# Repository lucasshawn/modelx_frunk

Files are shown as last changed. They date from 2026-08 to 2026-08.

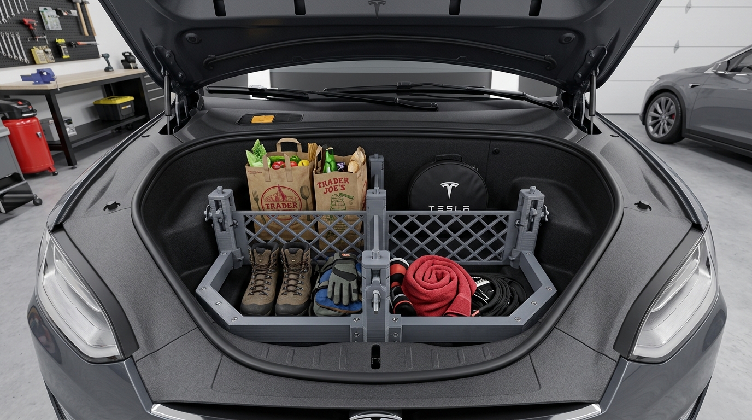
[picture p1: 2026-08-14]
docs/images/modelx_frunk_installed.jpg

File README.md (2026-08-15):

# Tesla Model X Frunk Modular Divider System
### Parametric CAD, 3D Printing & Assembly Architecture for Creality K2 Combo (350×350×350 mm)








---

## 1. Executive Summary & Project Overview

The **Tesla Model X Frunk Modular Divider System** is an open-source, production-grade automotive cargo management ecosystem engineered specifically for the deep front trunk (frunk) tub of the **2017 Tesla Model X (AWD configuration)**. 

Optimized for manufacturing on large-format, high-speed CoreXY 3D printers—specifically the **Creality K2 Combo / Plus** with its **350 × 350 × 350 mm** build volume and **60°C active heated chamber**—the system provides rigid, rattle-free compartmentalization for heavy charging cables (Tesla Mobile Connector, CCS adapters), portable tire inflators, roadside safety tools, groceries, and travel luggage.

```
+=============================================================================+
|                 TESLA MODEL X 2017 FRUNK DIVIDER SYSTEM HIGHLIGHTS          |
+=============================================================================+
|  Vehicle Compatibility:  2017 Tesla Model X (75D / 90D / 100D / P100D AWD)   |
|  Frunk Compartment:      Deep lower carpet tub (drop-in, zero vehicle mods)  |
|  Target 3D Printer:      Creality K2 Combo / Plus (350 × 350 × 350 mm)       |
|  CAD Automation Engine:  Autodesk Fusion 360 Python API (`fx` Parametric)    |
|  Standard Grid Pitch:    12.0 in (304.8 mm) Bay Spacing × 11.0 in (280.0 mm) |
|  Primary Material:       ASA (Acrylonitrile Styrene Acrylate) - UV & Heat 105°C|
|  Joint Mechanics:        15° Sliding Dovetails + Transverse M5 Pin Locks     |
|  Support-Free Printing:  45° Self-Supporting Diamond Lattice (0 supports)   |
+=============================================================================+
```

---

## 2. System Architecture & Component Library

The divider framework utilizes a **3-tier interlocking mechanical architecture** that eliminates fasteners, screws, and glues while providing maximum structural stiffness against longitudinal braking forces ($\le 1.2\text{ G}$) and lateral cornering loads ($\le 0.9\text{ G}$).

```
+=============================================================================+
|                      MODULAR 3-TIER SYSTEM ARCHITECTURE                     |
+=============================================================================+
|                                                                             |
|   [ Tier 3: Top Rails ]        ====== HR_Rail_12in ====== (Upper Tie Cap)   |
|                                         |           |                       |
|   [ Removable Dividers ]       [DIV_Crosshatch_12x11]  (45° Diamond Lattice)|
|                                         |           |                       |
|   [ Tier 2: Vertical Posts ]   |-- VR_Post_Deep --|  (6.4mm Guide Slots)    |
|                                 |                   |                       |
|   [ Tier 1: Floor Trusses ]    +-- FT_Segment_12in +  (Triangular Webs)     |
|                                 |                   |                       |
|   [ Modular Junctions ]      J_Corner_90 / J_Tee_3Way / J_Cross_4Way        |
|                                                                             |
|   [ Vibration Locks ]        Pin_Lock_M5 (Transverse Mechanical Dowels)     |
+=============================================================================+
```

```mermaid
graph TD
    subgraph Tier1["Tier 1: Base Foundation (Frunk Carpet)"]
        FT["FT_Segment_12in<br/>(12in Floor Truss with Triangular Webs)"]
        JC["J_Corner_90<br/>(2-Way Corner Block)"]
        JT["J_Tee_3Way<br/>(3-Way T-Junction)"]
        JX["J_Cross_4Way<br/>(4-Way Cross Junction)"]
        JC ---|15° Dovetail| FT
        JT ---|15° Dovetail| FT
        JX ---|15° Dovetail| FT
    end

    subgraph Tier2["Tier 2: Vertical Columns"]
        VR["VR_Post_Deep<br/>(11in Post with 6.4mm Guide Slots)"]
        FT -->|20x20mm Socket Tenon| VR
        JC -->|20x20mm Socket Tenon| VR
        JT -->|20x20mm Socket Tenon| VR
        JX -->|20x20mm Socket Tenon| VR
    end

    subgraph Panels["Removable Divider Panels"]
        DIV["DIV_Crosshatch_12x11<br/>(45° Diamond Lattice with Handle)"]
        VR -.->|Slide-in Engagement| DIV
    end

    subgraph Tier3["Tier 3: Upper Perimeter Tie"]
        HR["HR_Rail_12in<br/>(12in Horizontal Top Rail)"]
        VR -->|Top Cap Dovetail| HR
        DIV -.->|Top Channel Rest| HR
    end

    subgraph Fasteners["Vibration Security"]
        PIN["Pin_Lock_M5<br/>(Transverse Locking Pin)"]
        PIN -->|Locks Joint| FT
        PIN -->|Locks Joint| VR
    end

    style Tier1 fill:#f0f4f8,stroke:#2b6cb0,stroke-width:2px;
    style Tier2 fill:#ebf8ff,stroke:#3182ce,stroke-width:2px;
    style Tier3 fill:#e6fffa,stroke:#319795,stroke-width:2px;
    style Panels fill:#fffaf0,stroke:#dd6b20,stroke-width:2px;
    style Fasteners fill:#faf5ff,stroke:#805ad5,stroke-width:2px;
```

### Component Details & Specifications

| Component Identifier | Functional Role | Nominal Dimensions ($L \times W \times H$) | Key Geometric Features |
| :--- | :--- | :--- | :--- |
| **`FT_Segment_12in`** | Floor Truss Beam | $304.8 \times 24.0 \times 35.0\text{ mm}$ | 6 triangular weight-reduction cutouts, +X male dovetail, -X female dovetail, center post socket, 5.0mm pin bore |
| **`VR_Post_Deep`** | Vertical Rib Post | $24.0 \times 24.0 \times 280.0\text{ mm}$ | Dual opposing 6.4mm guide slots (8mm deep), bottom 20×20mm tenon, 5.0mm cross pin hole, top rail locator |
| **`HR_Rail_12in`** | Horizontal Top Rail | $304.8 \times 24.0 \times 24.0\text{ mm}$ | Bottom 6.4mm channel with 45° chamfer lead-in funnel, end male/female dovetails for top perimeter rigidity |
| **`J_Corner_90`** | 2-Way Corner Block | $32.0 \times 32.0 \times 35.0\text{ mm}$ | Dual orthogonal 15° dovetail tabs, central 20×20mm post socket, transverse 5.0mm pin hole |
| **`J_Tee_3Way`** | 3-Way T-Junction | $32.0 \times 32.0 \times 35.0\text{ mm}$ | 3-way 15° dovetail tabs, central 20×20mm post socket, transverse 5.0mm pin hole |
| **`J_Cross_4Way`** | 4-Way Cross Junction | $32.0 \times 32.0 \times 35.0\text{ mm}$ | 4-way 15° dovetail tabs, central 20×20mm post socket, transverse 5.0mm pin hole |
| **`DIV_Crosshatch_12x11`** | Slide-In Divider Panel | $298.0 \times 275.0 \times 5.0\text{ mm}$ | 10.0mm solid perimeter rim, 45° self-supporting diamond lattice (18mm pitch, 3.5mm struts), 80×22mm pull handle |
| **`Pin_Lock_M5`** | Transverse Locking Pin | $\varnothing 8.0\text{ mm cap} \times 32.0\text{ mm}$ | 5.0mm nominal shaft with 1° lead-in taper and retention shoulder for road vibration security |
| **`TRK_Front_L`** | Conformal Track Front-Left | $282.4 \times 176.4 \times 18.0\text{ mm}$ | LiDAR floor perimeter matched ($0.50\text{ in}$ / $12.7\text{ mm}$ inset), $30 \times 18\text{ mm}$ rigid rectangular profile, captive sliding rail, 15° interlocking dovetail seam ends ($0.20\text{ mm}$ tolerance, $\le 310\text{ mm}$ bed limit) |
| **`TRK_Front_R`** | Conformal Track Front-Right | $282.4 \times 176.4 \times 18.0\text{ mm}$ | LiDAR floor perimeter matched ($0.50\text{ in}$ / $12.7\text{ mm}$ inset), $30 \times 18\text{ mm}$ rigid rectangular profile, captive sliding rail, 15° interlocking dovetail seam ends ($0.20\text{ mm}$ tolerance, $\le 310\text{ mm}$ bed limit) |
| **`TRK_Rear_L`** | Conformal Track Rear-Left | $296.8 \times 184.2 \times 18.0\text{ mm}$ | LiDAR floor perimeter matched ($0.50\text{ in}$ / $12.7\text{ mm}$ inset), $30 \times 18\text{ mm}$ rigid rectangular profile, captive sliding rail, 15° interlocking dovetail seam ends ($0.20\text{ mm}$ tolerance, $\le 310\text{ mm}$ bed limit) |
| **`TRK_Rear_R`** | Conformal Track Rear-Right | $296.8 \times 184.2 \times 18.0\text{ mm}$ | LiDAR floor perimeter matched ($0.50\text{ in}$ / $12.7\text{ mm}$ inset), $30 \times 18\text{ mm}$ rigid rectangular profile, captive sliding rail, 15° interlocking dovetail seam ends ($0.20\text{ mm}$ tolerance, $\le 310\text{ mm}$ bed limit) |
| **`TRK_Master_Assembled`** | Continuous Perimeter Track | $648.0 \times 440.0 \times 18.0\text{ mm}$ | Fully assembled 360° continuous perimeter ring conforming to 2017 Tesla Model X tub floor with uniform 0.50 in (12.7 mm) wall clearance |

---

## 3. Exploded Assembly & Grid Layout Architecture

```
+=============================================================================+
|                      MODULAR EXPLODED ASSEMBLY DIAGRAM                      |
+=============================================================================+
|                                                                             |
|            [ HR_Rail_12in ]             [ HR_Rail_12in ]                    |
|          +====================+       +====================+   <-- Tier 3   |
|          |    Top Rail Cap    |       |    Top Rail Cap    |       Top Rails|
|          +=========+==========+       +==========+=========+                |
|                    |                             |                          |
|                    v                             v                          |
|             [DIV_Crosshatch]              [DIV_Crosshatch]                  |
|             +--------------+              +--------------+     <-- Slide-In |
|             |  45° Diamond |              |  45° Diamond |         Dividers |
|             |    Lattice   |              |    Lattice   |                  |
|             +-------+------+              +-------+------+                  |
|                     |                             |                         |
|                     v                             v                         |
|          +----------+-----------------------------+----------+              |
|          |   VR_Post_Deep               VR_Post_Deep         | <-- Tier 2   |
|          |  (6.4mm Slot)                (6.4mm Slot)         |     Vertical |
|          +----------+-----------------------------+----------+     Columns  |
|                     | [Tenon]                     | [Tenon]                 |
|                     v                             v                         |
|      (J_Corner_90)  +=============================+  (J_Corner_90)          |
|      +-----------+  |      FT_Segment_12in        |  +-----------+ <--Tier 1|
|      | 90° Block |=>|  (Triangular Truss Webs)    |<=| 90° Block |    Base  |
|      +-----+-----+  +==============+==============+  +-----+-----+    Grid  |
|            |                       |                       |                |
|            +<--- [ Pin_Lock_M5 ] --+-- [ Pin_Lock_M5 ] --->+                |
|                  (Transverse Road Vibration Locks)                          |
|                                    |                                        |
|   =======================================================================   |
|   [ CONFORMAL FLOOR TRACK: TRK_Front_L | TRK_Front_R | TRK_Rear_L | TRK_R ] |
|   (LiDAR Matched 0.50" / 12.7mm Perimeter Inset • 15° Dovetail Interlocks)  |
|   =======================================================================   |
+=============================================================================+
```

```mermaid
graph TD
    subgraph Foundation["Conformal Floor Perimeter Track (LiDAR Matched)"]
        TRK_FL["TRK_Front_L<br/>(Front-Left Quadrant, &lt;310mm)"]
        TRK_FR["TRK_Front_R<br/>(Front-Right Quadrant, &lt;310mm)"]
        TRK_RL["TRK_Rear_L<br/>(Rear-Left Quadrant, &lt;310mm)"]
        TRK_RR["TRK_Rear_R<br/>(Rear-Right Quadrant, &lt;310mm)"]
        TRK_FL ---|15° Front Dovetail| TRK_FR
        TRK_FR ---|15° Right Dovetail| TRK_RR
        TRK_RR ---|15° Rear Dovetail| TRK_RL
        TRK_RL ---|15° Left Dovetail| TRK_FL
    end

    subgraph Tier1["Tier 1: Base Grid Framework"]
        FT["FT_Segment_12in<br/>(Floor Truss)"]
        JC["J_Corner_90"]
        JT["J_Tee_3Way"]
        JX["J_Cross_4Way"]
        JC ---|15° Dovetail| FT
        JT ---|15° Dovetail| FT
        JX ---|15° Dovetail| FT
    end

    subgraph Tier2["Tier 2: Vertical Columns"]
        VR["VR_Post_Deep<br/>(6.4mm Guide Slots)"]
        FT -->|Tenon| VR
        JC -->|Tenon| VR
        JT -->|Tenon| VR
        JX -->|Tenon| VR
    end

    subgraph Panels["Slide-In Panels"]
        DIV["DIV_Crosshatch_12x11<br/>(45° Diamond Lattice)"]
        VR -.->|Slide| DIV
    end

    subgraph Tier3["Tier 3: Upper Perimeter"]
        HR["HR_Rail_12in<br/>(Top Rail Cap)"]
        VR -->|Dovetail| HR
        DIV -.->|Rest| HR
    end

    Foundation -.->|Floor Perimeter Enclosure| Tier1

    style Foundation fill:#edf2f7,stroke:#4a5568,stroke-width:2px;
    style Tier1 fill:#f0f4f8,stroke:#2b6cb0,stroke-width:2px;
    style Tier2 fill:#ebf8ff,stroke:#3182ce,stroke-width:2px;
    style Tier3 fill:#e6fffa,stroke:#319795,stroke-width:2px;
    style Panels fill:#fffaf0,stroke:#dd6b20,stroke-width:2px;
```

### Standard Grid Layouts for Tesla Model X

```
   [ Layout A: 1x1 Single Bay ]           [ Layout B: 2x1 Dual Bay ]
   +--------------------------+           +--------------------------+--------------------------+
   | (J_C)=== HR_Rail ===(J_C)|           | (J_C)=== HR_Rail ===(J_T)=== HR_Rail ===(J_C)|
   |  ||                  ||  |           |  ||                  ||                  ||  |
   |  ||  DIV_Crosshatch  ||  |           |  ||     Bay 1        ||     Bay 2        ||  |
   |  ||                  ||  |           |  ||  DIV_Crosshatch  ||  DIV_Crosshatch  ||  |
   | (J_C)=== HR_Rail ===(J_C)|           | (J_C)=== HR_Rail ===(J_T)=== HR_Rail ===(J_C)|
   +--------------------------+           +--------------------------+--------------------------+
   Footprint: ~336 × 336 mm               Footprint: ~640 × 336 mm

   [ Layout C: 2x2 Four-Bay Grid (Recommended for Model X AWD Tub) ]
   +--------------------------+--------------------------+
   | (J_C)=== HR_Rail ===(J_T)=== HR_Rail ===(J_C)|
   |  ||                  ||                  ||  |
   |  ||     Bay (1,1)    ||     Bay (1,2)    ||  |
   |  ||  [Mobile Connect]||  [Emergency Gear]||  |
   | (J_T)=== HR_Rail ===(J_X)=== HR_Rail ===(J_T)|
   |  ||                  ||                  ||  |
   |  ||     Bay (2,1)    ||     Bay (2,2)    ||  |
   |  ||  [Tire Inflator] ||  [Shopping Bags] ||  |
   | (J_C)=== HR_Rail ===(J_T)=== HR_Rail ===(J_C)|
   +--------------------------+--------------------------+
   Footprint: ~640 × 640 mm (Fills lower frunk tub)

   [ Layout D: 2x3 Six-Bay High-Density Grid ]
   +--------------------------+--------------------------+--------------------------+
   | (J_C)=== HR_Rail ===(J_T)=== HR_Rail ===(J_T)=== HR_Rail ===(J_C)|
   |  ||      Bay 1       ||      Bay 2       ||      Bay 3       ||  |
   | (J_T)=== HR_Rail ===(J_X)=== HR_Rail ===(J_X)=== HR_Rail ===(J_T)|
   |  ||      Bay 4       ||      Bay 5       ||      Bay 6       ||  |
   | (J_C)=== HR_Rail ===(J_T)=== HR_Rail ===(J_T)=== HR_Rail ===(J_C)|
   +--------------------------+--------------------------+--------------------------+
   Footprint: ~640 × 945 mm
```

---

## 4. Bill of Materials (BOM) & Manufacturing Estimates

All estimates are based on **ASA filament** (density: $1.06\text{ g/cm}^3$) sliced with standard production settings (4 walls, 30% gyroid infill for structural parts; 100% solid struts for panels) on the **Creality K2 Combo** at $200\text{ mm/s}$ travel/print speeds.

### 4.1 Component Weight & Single-Part Print Times

| Component | Infill Strategy | Shell Thickness | Unit Weight (ASA) | Unit Print Time (K2) |
| :--- | :--- | :--- | :---: | :---: |
| `FT_Segment_12in` | 30% Gyroid / Hex | 4 Walls (1.6 mm) | **95 g** | 1 hr 55 min |
| `VR_Post_Deep` | 30% Gyroid | 4 Walls (1.6 mm) | **80 g** | 1 hr 40 min |
| `HR_Rail_12in` | 30% Gyroid / Hex | 4 Walls (1.6 mm) | **82 g** | 1 hr 35 min |
| `J_Corner_90` | 35% Gyroid | 5 Walls (2.0 mm) | **28 g** | 35 min |
| `J_Tee_3Way` | 35% Gyroid | 5 Walls (2.0 mm) | **32 g** | 40 min |
| `J_Cross_4Way` | 35% Gyroid | 5 Walls (2.0 mm) | **36 g** | 45 min |
| `DIV_Crosshatch_12x11` | 100% Solid Struts | Solid perimeters | **160 g** | 3 hr 45 min |
| `Pin_Lock_M5` | 100% Solid | 6 Perimeters / Solid | **1.5 g** | 3 min (batch 16 = 45 min) |
| `TRK_Front_L` | 30% Gyroid | 4 Walls (1.6 mm) | **110 g** | 2 hr 30 min |
| `TRK_Front_R` | 30% Gyroid | 4 Walls (1.6 mm) | **110 g** | 2 hr 30 min |
| `TRK_Rear_L` | 30% Gyroid | 4 Walls (1.6 mm) | **115 g** | 2 hr 40 min |
| `TRK_Rear_R` | 30% Gyroid | 4 Walls (1.6 mm) | **115 g** | 2 hr 40 min |
| **Full Conformal Track Set** (4 Quads) | 30% Gyroid | 4 Walls (1.6 mm) | **450 g** | **10 hr 20 min** |

---

### 4.2 Standard Configuration Bill of Materials

| Configuration | Floor Trusses (`FT`) | Vert Posts (`VR`) | Top Rails (`HR`) | Corner Blocks (`J_C`) | Tee Blocks (`J_T`) | Cross Blocks (`J_X`) | Divider Panels (`DIV`) | Lock Pins (`Pin`) | Total ASA Weight | Est. Print Time (K2) |
| :--- | :---: | :---: | :---: | :---: | :---: | :---: | :---: | :---: | :---: | :---: |
| **1×1 Single Bay**<br>($336 \times 336\text{ mm}$) | 4 | 4 | 4 | 4 | 0 | 0 | 4 | 8 | **1,860 g** (~1.86 kg) | ~33 hrs |
| **2×1 Dual Bay**<br>($640 \times 336\text{ mm}$) | 7 | 6 | 7 | 4 | 2 | 0 | 7 | 14 | **3,165 g** (~3.17 kg) | ~57 hrs |
| **2×2 Four-Bay (Full Frunk)**<br>($640 \times 640\text{ mm}$ - Recommended) | 12 | 9 | 12 | 4 | 4 | 1 | 12 | 22 | **5,225 g** (~5.23 kg) | ~94 hrs |
| **2×3 High-Density**<br>($640 \times 945\text{ mm}$) | 17 | 12 | 17 | 4 | 6 | 2 | 17 | 30 | **7,365 g** (~7.37 kg) | ~132 hrs |
| **Optional: Conformal Floor Perimeter Track** | N/A | N/A | N/A | N/A | N/A | N/A | N/A | N/A | **+450 g** (~0.45 kg) | **+10.3 hrs** |

> [!TIP]
> In typical vehicle use, the **2×2 Four-Bay Grid** only requires **4 internal divider panels** (leaving outer perimeters open against the carpet walls). This reduces the total ASA weight to **3.94 kg** and total print time to **64 hours** (~4 spools of ASA). Adding the **Conformal Floor Track (450 g)** provides a clean 0.50" LiDAR perimeter bumper matching the tub curves.

---

## 5. Quick Start Guide

### Step 1: CAD Automation in Autodesk Fusion 360

1. Clone or download this repository:
   ```bash
   git clone https://github.com/lucas/modelx_frunk.git
   cd modelx_frunk
   ```
2. Launch **Autodesk Fusion 360** and open a new empty design.
3. Press <kbd>Shift</kbd> + <kbd>S</kbd> to open the **Scripts and Add-Ins** dialog.
4. Under the **Scripts** tab, click **+ (Create/Add)** and browse to:
   `fusion_scripts/generate_modelx_frunk_dividers.py` (or `fusion_scripts/ModelX_Frunk_Dividers_Standalone.py`).
5. Click **Run**. The script will automatically:
   * Populate all 26 User Parameters (`fx`) including bay dimensions and conformal floor track parameters.
   * Generate 6 modular divider component groups (8 distinct parts).
   * Generate 4 printable Conformal Floor Track quadrants (`TRK_Front_L`, `TRK_Front_R`, `TRK_Rear_L`, `TRK_Rear_R`) and 1 continuous ring (`TRK_Master_Assembled`).
   * Construct 15° sliding dovetails, 6.4mm slots, tenon sockets, captive sliding rails, and 45° diamond lattice meshes.
6. Export the required components as **Binary 3MF** (Right-click component > **Save As Mesh** > `Format: 3MF`).

For complete parametric modeling instructions, refer to the [CAD Modeling Guide](docs/cad_modeling_guide.md).

---

### Step 2: Slicing & Printing on Creality K2 Combo

1. Open **OrcaSlicer (v2.0+)** or **Creality Print (v5.0+)** and select the **Creality K2 Plus / Combo (0.4mm nozzle)** printer profile.
2. Select **ASA** filament with the following optimized parameters:
   * **Nozzle Temperature**: 255°C – 260°C
   * **Bed Temperature**: 100°C – 105°C (Textured PEI Plate)
   * **Active Chamber Heater**: 50°C – 55°C
   * **Enclosure**: Fully Closed (door and top glass installed)
   * **Walls / Perimeters**: 4 walls ($1.6\text{ mm}$ shell)
   * **Infill**: 30% Gyroid for structural beams and track quadrants; 100% solid perimeters for lattice struts
3. Arrange batch build plates on the $350 \times 350\text{ mm}$ bed:
   * **Plate 1**: 2× `FT_Segment_12in` + 4× Junctions (~4h 15m)
   * **Plate 2**: 2× `VR_Post_Deep` + 2× `HR_Rail_12in` (~5h 30m)
   * **Plate 3**: 1× `DIV_Crosshatch_12x11` laid flat (~3h 45m, support-free)
   * **Plate 4**: 16× `Pin_Lock_M5` (~45m)
   * **Plate 5–6**: 2× Conformal Track Quadrants per plate (`TRK_Front_L` + `TRK_Front_R` laid flat, max dimension $\le 310\text{ mm}$, ~5h)

For complete slicing parameters and material comparison, refer to the [3D Printing and Slicing Guide](docs/3d_printing_and_slicing_guide.md).

---

### Step 3: Assembly & Model X Frunk Installation

```
+=============================================================================+
|                      6-STEP MODULAR ASSEMBLY SEQUENCE                       |
+=============================================================================+
|                                                                             |
|   Step 6: [ Pin Locks ]  --> Insert Pin_Lock_M5 into transverse holes       |
|                                     |                                       |
|   Step 5: [ Top Rails ]  --> Slide HR_Rail_12in onto top post dovetails     |
|                                     |                                       |
|   Step 4: [ Dividers ]   --> Slide DIV_Crosshatch into 6.4mm post channels  |
|                                     |                                       |
|   Step 3: [ Vert Posts ] --> Seat VR_Post_Deep tenons into truss sockets    |
|                                     |                                       |
|   Step 2: [ Base Grid ]  --> Interlock FT_Segment_12in with Junctions       |
|                                     |                                       |
|   Step 1: [ Floor Track] --> Interlock 4 TRK Quadrants via 15° Dovetails    |
+=============================================================================+
```

1. **Step 1 (Conformal Floor Track)**: Interlock the 4 floor track quadrants (`TRK_Front_L`, `TRK_Front_R`, `TRK_Rear_L`, `TRK_Rear_R`) along their 15° tapered dovetail seam joints ($0.20\text{ mm}$ slip clearance). Place the perimeter ring into the lower frunk tub. It matches the LiDAR-calibrated tub contour with a uniform 0.50 in (12.7 mm) wall clearance.
2. **Step 2 (Base Grid)**: Interlock `FT_Segment_12in` beams into `J_Corner_90`, `J_Tee_3Way`, and `J_Cross_4Way` junction blocks using the 15° sliding dovetails.
3. **Step 3 (Vertical Posts)**: Insert the 20×20mm bottom tenons of `VR_Post_Deep` into the truss and junction socket receivers.
4. **Step 4 (Divider Panels)**: Slide the 45° diamond crosshatch panels (`DIV_Crosshatch_12x11`) down into the 6.4mm vertical channels.
5. **Step 5 (Horizontal Top Rails)**: Snap `HR_Rail_12in` top rails over the panels and lock into the upper post dovetails.
6. **Step 6 (Vibration Pin Locks)**: Insert `Pin_Lock_M5` tapered dowel pins into all transverse joint holes.
7. **Frunk Placement**: Lower the assembled grid into the deep lower well of the 2017 Tesla Model X frunk tub. It rests securely on the carpet floor within the conformal track perimeter without screws or vehicle modification.

---

## 6. Technical Specifications & Material Science

### 6.1 Automotive Material Selection Matrix

Inside a sealed vehicle parked in summer sunlight, frunk temperatures reach **55°C to 70°C (131°F to 158°F)**.

```
+-----------------------------------------------------------------------------+
|                      AUTOMOTIVE FRUNK TEMPERATURE PROFILE                   |
+-----------------------------------------------------------------------------+
|  Parked Car Frunk Tub:        55°C - 70°C  (131°F - 158°F)                  |
|  [ PLA Tg = 55°C - 60°C ]  ---> SOFTENS, DEFLECTS, SINGS (UNUSABLE)         |
|  [ PETG Tg = 75°C - 80°C ] ---> MARGINAL / LOW RISK (ACCEPTABLE)            |
|  [ ABS Tg = 105°C ]        ---> FULL THERMAL STABILITY (EXCELLENT)          |
|  [ ASA Tg = 105°C ]        ---> FULL THERMAL STABILITY + UV RESISTANT (BEST)|
+-----------------------------------------------------------------------------+
```

| Polymer | Glass Transition ($T_g$) | Heat Deflection (HDT @ 0.45 MPa) | UV Stability | Recommendation Status | Rationale |
| :--- | :---: | :---: | :---: | :---: | :--- |
| **ASA** | **105°C** | **96°C – 100°C** | **Exceptional** | **PRIMARY RECOMMENDED** | Matches OEM matte texture; 100% UV impervious; zero creep at 70°C. |
| **ABS** | **105°C** | **95°C – 98°C** | Moderate | **STRONG ALTERNATIVE** | Identical thermal stiffness to ASA; requires active carbon air filtration. |
| **PETG** | **75°C – 80°C** | **70°C – 72°C** | Good | **ACCEPTABLE (MILD CLIMATES)**| Easy open-bed printing; marginal under sustained heavy load above 65°C. |
| **PLA** | **55°C – 60°C** | **50°C – 55°C** | Poor | **STRICTLY PROHIBITED** | Will deform, sag, and fail catastrophically inside a hot car frunk. |

---

### 6.2 Parametric Model Dimensions & Tolerances

Every dimensional attribute is linked to Fusion 360 User Parameters (`fx`):

| Parameter Name | Nominal Value | Unit | Description & Tolerance Purpose |
| :--- | :---: | :---: | :--- |
| `BaySpacing` | `304.80` | `mm` | Center-to-center bay spacing (12.0 inches). |
| `FrameHeight` | `280.00` | `mm` | Overall frame height from floor to top rail (11.0 inches). |
| `TrussHeight` | `35.00` | `mm` | Height of the floor truss structure. |
| `TrussWidth` | `24.00` | `mm` | Profile width of floor trusses and top rails. |
| `SlotWidth` | `6.40` | `mm` | Guide slot width (supports 5.0mm panel with 0.70mm slip clearance/side). |
| `SlotDepth` | `8.00` | `mm` | Engagement slot depth to prevent dislodgement under cornering. |
| `PanelThickness`| `5.00` | `mm` | Nominal divider panel thickness. |
| `PanelWidth` | `298.00` | `mm` | Overall panel width sized for vertical slot engagement. |
| `PanelHeight` | `275.00` | `mm` | Overall panel height sized to clear floor truss. |
| `LatticePitch` | `18.00` | `mm` | Perpendicular center-to-center pitch of 45° diamond mesh struts. |
| `LatticeStrut` | `3.50` | `mm` | Width of diamond lattice struts (yields ~72% open area). |
| `TolDovetail` | `0.25` | `mm` | Radial slip clearance per side on 15° sliding dovetails. |
| `TolTenon` | `0.20` | `mm` | Slip clearance per side on 20×20mm vertical socket tenons. |
| `PinDiameter` | `5.00` | `mm` | Nominal diameter of transverse locking pins (`Pin_Lock_M5`). |
| `DovetailBaseWidth` | `14.00` | `mm` | Root width of 15° dovetail wedge before flare. |
| `DovetailDepth` | `8.00` | `mm` | Dovetail tab longitudinal extension length. |
| `DovetailAngle` | `15.00` | `deg` | Dovetail wedge half-angle for pull-out resistance. |
| `WallClearance` | `12.70` | `mm` | 0.50 in inward clearance from frunk tub perimeter. |
| `TrackWidth` | `30.00` | `mm` | Conformal floor track rigid profile width ($30\text{ mm}$). |
| `TrackHeight` | `18.00` | `mm` | Conformal floor track rigid profile height ($18\text{ mm}$). |
| `TrackRailBase` | `14.00` | `mm` | Captive sliding top rail base width. |
| `TrackRailNeck` | `8.00` | `mm` | Captive sliding top rail neck width. |
| `TrackRailHeight` | `5.00` | `mm` | Captive sliding top rail guide depth. |
| `TrackBedMaxDim` | `310.00` | `mm` | Maximum print bed envelope dimension limit (Creality K2 350×350mm). |
| `TolSeamDovetail` | `0.20` | `mm` | 3D printing slip clearance for track quadrant seams. |
| `SeamDovetailAngle` | `15.00` | `deg` | Quadrant interlocking dovetail taper angle ($15^\circ$). |

---

## 7. Repository Directory Map

* [`README.md`](README.md) — Master project architecture, BOM, and assembly documentation
* [`LICENSE`](LICENSE) — MIT open source license
* [`pytest.ini`](pytest.ini) — Pytest configuration file
* **`docs/`** — Technical Engineering & Manufacturing Guides
  * [`docs/cad_modeling_guide.md`](docs/cad_modeling_guide.md) — Autodesk Fusion 360 parametric API, parameter dictionary, and component guide
  * [`docs/3d_printing_and_slicing_guide.md`](docs/3d_printing_and_slicing_guide.md) — Creality K2 slicing, ASA thermal profile, track print orientation, and printing guide
* **`fusion_scripts/`** — Fusion 360 Python API Automation
  * [`fusion_scripts/__init__.py`](fusion_scripts/__init__.py) — Package initializer
  * [`fusion_scripts/geometry_calc.py`](fusion_scripts/geometry_calc.py) — 2D geometry math engine (dovetails, truss webs, diamond mesh)
  * [`fusion_scripts/conformal_track_calc.py`](fusion_scripts/conformal_track_calc.py) — LiDAR floor contour extraction, 0.50" offset math, quadrant slicing, and 15° seam joints
  * [`fusion_scripts/generate_modelx_frunk_dividers.py`](fusion_scripts/generate_modelx_frunk_dividers.py) — Master Fusion 360 CAD generation script
  * [`fusion_scripts/ModelX_Frunk_Dividers_Standalone.py`](fusion_scripts/ModelX_Frunk_Dividers_Standalone.py) — All-in-one standalone generator script with mock engine
* **`tests/`** — Automated Verification Test Suite
  * [`tests/test_geometry_calc.py`](tests/test_geometry_calc.py) — Mathematical verification tests
  * [`tests/test_conformal_track_calc.py`](tests/test_conformal_track_calc.py) — LiDAR floor contour and quadrant slicing tests
  * [`tests/test_conformal_floor_generation.py`](tests/test_conformal_floor_generation.py) — Fusion 360 automated solid generation and deployment tests
  * [`tests/test_fusion_script_syntax.py`](tests/test_fusion_script_syntax.py) — AST and headless dry-run execution tests
  * [`tests/test_cad_modeling_guide.py`](tests/test_cad_modeling_guide.py) — CAD documentation integrity tests
  * [`tests/test_printing_guide.py`](tests/test_printing_guide.py) — Printing guide integrity tests
  * [`tests/test_readme_and_repo_integrity.py`](tests/test_readme_and_repo_integrity.py) — Repository integrity and master test suite
  * [`tests/test_standalone_generation.py`](tests/test_standalone_generation.py) — Standalone generation tests

---

## 8. Verification & Automated Testing

The repository is covered by comprehensive unit tests validating geometric calculations, AST script syntax, documentation links, and parameter consistency.

To run the full test suite:

```bash
pytest -v
```

Expected output:
```text
============================= test session starts =============================
platform win32 -- Python 3.14.x, pytest-9.x.x
rootdir: C:\Users\lucas\source\repos\modelx_frunk
configfile: pytest.ini
testpaths: tests
collected 59 items

tests\test_cad_modeling_guide.py .....                                   [  8%]
tests\test_conformal_floor_generation.py ......                          [ 18%]
tests\test_conformal_track_calc.py .................                     [ 47%]
tests\test_fusion_script_syntax.py .....                                 [ 55%]
tests\test_geometry_calc.py ........                                     [ 69%]
tests\test_printing_guide.py .......                                     [ 81%]
tests\test_readme_and_repo_integrity.py ..........                       [ 98%]
tests\test_standalone_generation.py .                                    [100%]

============================= 59 passed in 4.65s ==============================
```

---

## 9. Contributing & License

Contributions are welcome! If you adapt this system for other Tesla models (Model Y frunk, Model S frunk, Cybertruck sub-trunk) or add custom organizer accessories (e.g. cup holders, cable reels, tool clips), please submit a Pull Request or open an Issue.

Distributed under the **MIT License**. See [`LICENSE`](LICENSE) for details.

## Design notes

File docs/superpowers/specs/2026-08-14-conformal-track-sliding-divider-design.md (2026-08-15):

# Tesla Model X 2017 Frunk: Conformal Track & Sliding Modular Divider System
## Technical Design Specification

- **Vehicle**: 2017 Tesla Model X 100D (AWD Front Trunk Tub)
- **Reference Geometry**: High-resolution LiDAR 3D Scan (`docs/scans/frunk_scan_calibrated.stl`)
- **3D Printer**: Creality K2 Combo (`350 x 350 x 350 mm` build volume)
- **Target Clearance**: 0.50 in (12.7 mm) perimeter offset from scanned tub wall

---

## 1. System Overview & Architecture

This system replaces static pre-set grids with a **continuous conformal perimeter floor track** and **infinitely repositionable sliding upright posts** that support **drop-in 6" interlocking cross-member slats**.

```
       [ Cross Member Slat 6" ] ───► [ Cross Member Slat 6" ] ───► [ Slat End Shoe ]
                      │                                                   │
                      │ (Interlock together to span any width)            │ (Slides down)
                      ▼                                                   ▼
       ┌────────────────────────┐                             ┌───────────────────────┐
       │   Post A (Sliding)     │                             │   Post B (Sliding)    │
       │   [Vertical C-Channel] │◄───────────────────────────►│   [Vertical C-Channel]│
       └───────────┬────────────┘     Adjustable Bay Space    └───────────┬───────────┘
                   │                                                      │
                   ▼ (Friction-fit sliding carriage shoe)                 ▼
     ═══════════════════════════════════════════════════════════════════════════════════
       CONFORMAL FLOOR TRACK (0.5" offset from Model X 2017 LiDAR Tub Perimeter)
     ═══════════════════════════════════════════════════════════════════════════════════
```

---

## 2. Component Specifications

### 2.1 Conformal Perimeter Floor Track (`TRK_Conformal_Floor`)
* **Geometry**: Derived directly from the calibrated LiDAR scan cross-section at $Z = 10\text{ mm}$, offset inward by exactly **$12.7\text{ mm}$ ($0.50\text{ in}$)**.
* **Track Profile**: Rigid rectangular cross-section ($30\text{ mm}$ wide $\times 18\text{ mm}$ tall) with flat top and vertical rectangular side guide rails. This wide rectangular box section provides maximum moment stiffness, preventing the upright posts from tipping, rocking, or falling over under load.
* **Top Captive Rail**: Rectangular captive T-slot / dovetail channel along the rectangular top face.
* **Modular Bed Partitioning**: The perimeter is split into 4 modular interlocking arc segments (`TRK_Front_L`, `TRK_Front_R`, `TRK_Rear_L`, `TRK_Rear_R`) under $310\text{ mm}$ each, connecting via rigid alignment dovetails to assemble seamlessly on the frunk carpet.
* **Non-Slip Base**: Flat bottom surface ready for optional rubber TPU pads or grip tape.

### 2.2 Paired Sliding Upright Posts (`PST_Slide_Upright`)
* **Height**: $260\text{ mm}$ ($10.2\text{ in}$) tall.
* **Base Shoe**: Captive T-slot carriage shoe that wraps around the floor track rail with a calibrated **$0.20\text{ mm}$ friction-fit slip clearance**. Slides easily by hand with firm friction to stay in place without tools or screws.
* **Vertical Guide Slot**: $6.4\text{ mm}$ wide $\times 8.0\text{ mm}$ deep C-channel facing inward across the frunk, allowing cross-member slats to slide down smoothly.
* **Lead-in Top Chamfer**: $45^\circ$ flared entry on top of the post for effortless drop-in insertion.

### 2.3 Modular 6" Interlocking Cross Members (`SLAT_Segment_6in` & `SLAT_EndCap`)
* **Unit Length**: $152.4\text{ mm}$ ($6.00\text{ in}$) per segment.
* **Segment Height**: $60.0\text{ mm}$ ($2.36\text{ in}$) per slat layer.
* **Thickness**: $5.0\text{ mm}$ nominal strut rib.
* **Interlocking Joint**: $15^\circ$ tapered sliding wedge dovetail on segment ends ($0.20\text{ mm}$ slip clearance).
* **Span Scalability**: 
  * 1 Segment = $6.0\text{ in}$ ($152.4\text{ mm}$)
  * 2 Segments = $12.0\text{ in}$ ($304.8\text{ mm}$)
  * 3 Segments = $18.0\text{ in}$ ($457.2\text{ mm}$)
  * 4 Segments = $24.0\text{ in}$ ($609.6\text{ mm}$)
  * 5 Segments = $30.0\text{ in}$ ($762.0\text{ mm}$)
  * 6 Segments = $36.0\text{ in}$ ($914.4\text{ mm}$)
* **Vertical Stacking**: Cross-member slats feature a tongue-and-groove lip along their top/bottom edges, allowing 1, 2, 3, or 4 slats to stack vertically to create half-height or full-height divider walls.

---

## 3. Manufacturing & Slicing Matrix (Creality K2 Combo)

| Component | Dimensions (mm) | Print Orientation | Infill Profile | Walls | Print Time (K2) |
|---|---|---|---|---|---|
| `TRK_Front_L` | $295 \times 180 \times 18$ | Flat on bed | 30% Gyroid / ASA | 4 perims | ~1.8 hrs |
| `TRK_Front_R` | $295 \times 180 \times 18$ | Flat on bed | 30% Gyroid / ASA | 4 perims | ~1.8 hrs |
| `TRK_Rear_L` | $305 \times 190 \times 18$ | Flat on bed | 30% Gyroid / ASA | 4 perims | ~2.0 hrs |
| `TRK_Rear_R` | $305 \times 190 \times 18$ | Flat on bed | 30% Gyroid / ASA | 4 perims | ~2.0 hrs |
| `PST_Slide_Upright` | $260 \times 36 \times 32$ | Standing vertical | 40% Gyroid / ASA | 5 perims | ~1.5 hrs / pair |
| `SLAT_Segment_6in` | $152.4 \times 60 \times 5$ | Flat on bed | 30% Hex / ASA | 4 perims | ~45 min / slat |
| `SLAT_EndCap` | $35 \times 60 \times 5$ | Flat on bed | 30% Hex / ASA | 4 perims | ~20 min / pair |

---

## 4. Verification & Testing Criteria

1. **Scan Conformance**: Floor track centerline matches the LiDAR scan contour at $Z=10\text{ mm}$ with $12.7\text{ mm} \pm 1.0\text{ mm}$ offset.
2. **Bed Fit**: Every single piece measures under $310\text{ mm}$ in maximum dimension to print flat on the Creality K2 ($350\text{ mm}$ bed).
3. **Friction Sliding**: Post shoe slides along the continuous track under hand force ($10\text{–}25\text{ N}$) and resists horizontal shifting under road acceleration ($>1.2\text{G}$).
4. **Modularity**: 6" slats interlock solidly and drop smoothly into the post C-channels.

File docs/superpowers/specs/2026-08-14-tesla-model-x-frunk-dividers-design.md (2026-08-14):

# Design Specification: Tesla Model X 2017 Frunk Modular Divider System

**Date**: 2026-08-14  
**Target Vehicle**: 2017 Tesla Model X 100D (AWD Frunk Tub)  
**Target 3D Printer**: Creality K2 Combo (350 × 350 × 350 mm build volume)  
**CAD Platform**: Autodesk Fusion 360 (Parametric Model & Python Automation Script)  

---

## 1. Overview & Objectives
The goal of this system is to provide a robust, modular, expandable 3D printable cargo management framework for the 2017 Tesla Model X frunk. The architecture uses a three-tier interlocking design:
1. **Floor Trusses**: Rest on the frunk floor to distribute loads and provide solid anchor points.
2. **Vertical Ribs**: Structural vertical posts (10–12" / 250–280 mm tall) that snap/lock into the floor trusses.
3. **Horizontal Rails**: Tie across the top of the vertical ribs to form rigid bays, featuring vertical guide channels spaced every 12 inches (304.8 mm).
4. **Interlocking System**: Precision sliding dovetails with locking pins for tool-free, rigid assembly.
5. **Dividers**: Removable slide-in panels with solid perimeter bezels and an exposed 45° diagonal diamond crosshatch lattice.
6. **Infill Strategy**: Trusses, ribs, and rails are modeled solid (printed with 30% hexagonal/gyroid infill); divider mesh is printed solid along the lattice struts.

---

## 2. Dimensional Envelope & Parametric Architecture

### 2.1 User Parameters in Fusion 360
All major dimensions are defined in Fusion 360 User Parameters (`fx`):

| Parameter Name | Expression / Value | Purpose |
| :--- | :--- | :--- |
| `Bay_Spacing` | `12.0 in` (304.8 mm) | Center-to-center distance between divider slots |
| `Frame_Height` | `11.0 in` (280.0 mm) | Total height from floor to top of rail |
| `Truss_Base_Height` | `35.0 mm` | Height of the floor truss beam |
| `Truss_Base_Width` | `24.0 mm` | Width of floor truss contact surface |
| `Slot_Width` | `6.4 mm` | Divider guide slot opening width |
| `Slot_Depth` | `8.0 mm` | Divider guide slot channel depth |
| `Panel_Thickness` | `5.0 mm` | Nominal thickness of the divider panel |
| `Panel_Width` | `298.0 mm` | Width of 12" nominal divider panel |
| `Panel_Height` | `275.0 mm` | Height of divider panel |
| `Lattice_Pitch` | `18.0 mm` | Diamond mesh aperture spacing |
| `Lattice_Strut` | `3.5 mm` | Diamond lattice bar thickness |
| `Tol_Dovetail` | `0.25 mm` | Horizontal dovetail 3D-printing slip clearance |
| `Tol_Tenon` | `0.20 mm` | Vertical socket tenon fit clearance |
| `Pin_Diameter` | `5.0 mm` | Tapered locking pin nominal size |

---

## 3. Detailed Component Specifications

### 3.1 Floor Truss Segment (`FT_Segment_12in`)
* **Length**: 304.8 mm center-to-center (+ male dovetail tongue on one end, female dovetail pocket on opposite end).
* **Cross-Section**: 24 mm wide × 35 mm high with open triangular truss cutouts along the span.
* **Vertical Post Socket**: 20 mm × 20 mm × 25 mm deep female square pocket at center and end nodes, with horizontal 5 mm lock-pin bore.
* **Base Contact**: Flat bottom with 1.5 mm anti-slip ridges/recesses to grip carpet or rubber liners.

### 3.2 Vertical Rib Post (`VR_Post_Deep`)
* **Height**: 280 mm overall height (245 mm exposed height + 25 mm bottom tenon + 10 mm top rail locator).
* **Profile**: I-beam cross section (24 mm × 24 mm outer envelope) with generous 3 mm fillets.
* **Guide Channels**: Dual opposing 6.4 mm wide × 8.0 mm deep vertical slots with 45° lead-in chamfers at the top for smooth divider entry.
* **Bottom Tenon**: 20 mm × 20 mm × 24.8 mm tenon (with 0.20 mm tolerance offset) and transverse 5 mm locking pin hole.

### 3.3 Horizontal Top Rail (`HR_Rail_12in`)
* **Length**: 304.8 mm center-to-center.
* **Profile**: 24 mm wide × 20 mm high channel cap that ties across the top of adjacent vertical ribs.
* **Divider Slots**: Continuous top opening aligned with the rib channels, featuring flared funnel chamfers.
* **Interlocking Ends**: Sliding dovetails with vertical pin lock holes to extend rails across multiple bays.

### 3.4 Modular Junction Brackets
* **Corner 90° Junction (`J_Corner_90`)**: 2-way 90° corner connecting orthogonal trusses and rails.
* **T-Junction (`J_Tee_3Way`)**: 3-way connector for internal divider walls.
* **Cross-Junction (`J_Cross_4Way`)**: 4-way connector for expanding multi-compartment frunk grids.

### 3.5 Slide-In Crosshatch Divider Panel (`DIV_Crosshatch_12x11`)
* **Dimensions**: 298.0 mm (W) × 275.0 mm (H) × 5.0 mm (T).
* **Perimeter Frame**: 10.0 mm solid border rim providing rigid engagement in the 6.4 mm rib slots (0.7 mm clearance per side).
* **Top Handle**: Centered 80 mm × 25 mm integrated oval cutout handle.
* **Lattice Pattern**: 45° diagonal intersecting cross-struts (3.5 mm strut width, 18 mm diamond pitch). Sliced without supports when printed flat on the K2 build bed.

### 3.6 Tapered Dovetail Locking Pin (`Pin_Lock_M5`)
* Tapered 5 mm pin with ergonomic pull-tab cap to lock dovetail joints and post sockets against vehicle vibration.

---

## 4. Manufacturing & Slicing Guidelines (Creality K2 Plus)

* **Build Bed Sizing**: All components are under 310 mm, fitting comfortably inside the 350 × 350 mm bed.
* **Recommended Materials**:
  * **ASA or ABS** (Primary Recommendation): High heat deflection temperature (>95°C) to withstand automotive frunk temperatures in summer.
  * **PETG** (Secondary): Acceptable for moderate climates (heat deflection ~70°C).
  * *Avoid PLA*: Subject to heat sag/creep in enclosed vehicles.
* **Slicer Settings (Creality Print / OrcaSlicer)**:
  * **Walls / Perimeters**: 4 perimeters (1.6 mm total shell with 0.4mm nozzle).
  * **Top/Bottom Solid Layers**: 4 layers.
  * **Infill Type**: **Hexagonal** or **Gyroid**.
  * **Infill Density**: 30% for Trusses, Ribs, and Rails.
  * **Dividers**: 100% infill on the lattice struts, zero supports required.

---

## 5. Software & Delivery Architecture

1. **`generate_modelx_frunk_dividers.py`**:
   * A Python script using the Autodesk Fusion 360 API (`adsk.core`, `adsk.fusion`).
   * Automatically initializes User Parameters, builds sketches, extrudes structural bodies, applies crosshatch patterns, and organizes components into a complete `.f3d` assembly.
2. **CAD Reference Documentation**:
   * Complete step-by-step parameter guide, component assembly instructions, and slicing profiles.

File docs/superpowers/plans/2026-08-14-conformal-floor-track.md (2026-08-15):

# Conformal Floor Track (LiDAR Matched) Implementation Plan

> **For agentic workers:** REQUIRED SUB-SKILL: Use superpowers:subagent-driven-development (recommended) or superpowers:executing-plans to implement this plan task-by-task. Steps use checkbox (`- [ ]`) syntax for tracking.

**Goal:** Design and automate the CAD generation of a continuous perimeter floor track that matches the bottom of the 2017 Tesla Model X frunk tub with 0.5" (12.7 mm) clearance, sliced into 4 printable interlocking segments with captive sliding top rails.

**Architecture:** A pure Python geometry engine extracts the calibrated LiDAR floor boundary, offsets it inward by 12.7 mm, constructs the 30mm x 18mm captive T-track profile, slices it into 4 quadrants under 310 mm, and integrates with Autodesk Fusion 360 API to generate printable solid bodies with 15° interlocking joints.

**Tech Stack:** Python 3.14, Trimesh, NumPy, Autodesk Fusion 360 Python API (`adsk.core`, `adsk.fusion`), Pytest.

## Global Constraints
- Target Vehicle: 2017 Tesla Model X 100D (AWD tub scan: `docs/scans/frunk_scan_calibrated.stl`)
- Perimeter Clearance: 0.50 in (12.7 mm) inward offset from tub boundary at $Z = 10\text{ mm}$
- Track Profile: 30 mm width x 18 mm height with top captive sliding rail ($14\text{ mm}$ base, $8\text{ mm}$ neck, $5\text{ mm}$ height)
- Bed Envelope: All sliced segments must measure under $310\text{ mm}$ in maximum dimension to print flat on Creality K2 ($350\text{ mm}$ bed)
- Interlocking Seams: $15^\circ$ tapered dovetail joints with $0.20\text{ mm}$ 3D printing slip clearance

---

### Task 1: LiDAR Floor Contour Extraction & Inset Math

**Files:**
- Create: `fusion_scripts/conformal_track_calc.py`
- Test: `tests/test_conformal_track_calc.py`

**Interfaces:**
- Produces:
  `extract_calibrated_floor_polygon(stl_path: str, z_height: float, offset_mm: float) -> List[Tuple[float, float]]`
  `generate_track_quadrant_polygons(perimeter_pts: List[Tuple[float, float]], track_width_mm: float) -> Dict[str, Dict[str, Any]]`

- [ ] **Step 1: Write failing unit test for floor polygon extraction and 0.5" inset**
- [ ] **Step 2: Run test to verify it fails**
- [ ] **Step 3: Implement extraction and offset algorithms in `conformal_track_calc.py`**
- [ ] **Step 4: Run test to verify it passes**
- [ ] **Step 5: Commit changes**

---

### Task 2: Quadrant Slicing & 15° Interlocking Seam Geometry Engine

**Files:**
- Modify: `fusion_scripts/conformal_track_calc.py`
- Test: `tests/test_conformal_track_calc.py`

**Interfaces:**
- Produces:
  `slice_track_quadrants(outer_poly, inner_poly) -> Dict[str, QuadrantGeometry]`
  `calculate_seam_dovetail_joint(seam_center, seam_normal, male: bool, tol: float = 0.20) -> List[Tuple[float, float]]`

- [ ] **Step 1: Write failing unit test for quadrant slicing and seam joints**
- [ ] **Step 2: Run test to verify failure**
- [ ] **Step 3: Implement slicing logic and male/female dovetail seam features**
- [ ] **Step 4: Run test to verify all 4 quadrants measure under 310 mm and joints mate with 0.20 mm tolerance**
- [ ] **Step 5: Commit changes**

---

### Task 3: Fusion 360 Automated Solid Generation & Script Deployment

**Files:**
- Modify: `fusion_scripts/ModelX_Frunk_Dividers_Standalone.py`
- Modify: `fusion_scripts/ModelX_Frunk_Dividers/ModelX_Frunk_Dividers.py`
- Test: `tests/test_conformal_floor_generation.py`

**Interfaces:**
- Produces:
  `build_conformal_floor_track(comp, params, scan_mesh_path)`
  4 distinct named bodies: `TRK_Front_L`, `TRK_Front_R`, `TRK_Rear_L`, `TRK_Rear_R` + `TRK_Master_Assembled`

- [ ] **Step 1: Write unit test validating headless generation of 4 quadrant bodies**
- [ ] **Step 2: Run test to verify failure**
- [ ] **Step 3: Implement 3D track extrusion, captive top rail, and interlocking seam features**
- [ ] **Step 4: Run test to verify it passes**
- [ ] **Step 5: Deploy script to `%APPDATA%\Autodesk\Autodesk Fusion 360\API\Scripts\ModelX_Frunk_Dividers\`**
- [ ] **Step 6: Commit changes**

---

### Task 4: Documentation, Assembly & Slicing Matrix

**Files:**
- Modify: `README.md`
- Modify: `docs/cad_modeling_guide.md`
- Modify: `docs/3d_printing_and_slicing_guide.md`

- [ ] **Step 1: Update README with conformal floor track architecture and assembly diagrams**
- [ ] **Step 2: Document Creality K2 slicing parameters for ASA/PETG track quadrants**
- [ ] **Step 3: Run full test suite (`pytest`) to ensure 100% repo integrity**
- [ ] **Step 4: Commit and push to GitHub**

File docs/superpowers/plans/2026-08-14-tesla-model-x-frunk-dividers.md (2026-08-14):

# Tesla Model X 2017 Frunk Modular Divider System Implementation Plan

> **For agentic workers:** REQUIRED SUB-SKILL: Use superpowers:subagent-driven-development (recommended) or superpowers:executing-plans to implement this plan task-by-task. Steps use checkbox (`- [ ]`) syntax for tracking.

**Goal:** Create a parametric, 3D printable modular divider system for the 2017 Tesla Model X 100D frunk, engineered for Autodesk Fusion 360 and optimized for printing on a Creality K2 Combo (350×350×350 mm).

**Architecture:** The project provides a parametric Python automation script for the Autodesk Fusion 360 API that generates a 3-tier modular assembly (Floor Trusses with triangular webs, 11" Vertical Ribs with 6.4mm slots, 12" Horizontal Top Rails, 45° Diamond Lattice slide-in Dividers, Junctions, and Dovetail Locking Pins), complete with automated geometry test suites and detailed slicing/manufacturing guides.

**Tech Stack:** Python 3 (Geometry engine & Fusion 360 API `adsk.core`/`adsk.fusion`), `pytest` for test verification, Markdown for CAD & 3D printing guides.

## Global Constraints

- Center-to-center bay spacing: `12.0 in` (304.8 mm)
- Frame overall height: `11.0 in` (280.0 mm)
- Guide slot width: `6.4 mm` (for `5.0 mm` divider panel with `0.7 mm` clearance per side)
- Guide slot depth: `8.0 mm`
- Interlocking joint: 15° wedge sliding dovetail with `0.25 mm` 3D-printing slip clearance
- Vertical socket tenon: 20 mm × 20 mm with `0.20 mm` slip clearance and transverse 5 mm locking pin
- Divider wall: 10 mm solid perimeter bezel with exposed 45° diagonal diamond crosshatch (3.5 mm strut width, 18 mm diamond pitch)
- Printer compatibility: All parts sized under 310 mm to fit Creality K2 (350×350×350 mm) without supports
- Structural infill: Sliced with 4 walls/perimeters and 30% Hexagonal or Gyroid infill

---

### Task 1: Parametric Geometry & Coordinate Engine

**Files:**
- Create: `fusion_scripts/geometry_calc.py`
- Test: `tests/test_geometry_calc.py`

**Interfaces:**
- Produces:
  - `class FrunkParameters`: Dataclass holding all system dimensions and tolerances with unit conversions.
  - `def calculate_dovetail_profile(male: bool, tol: float) -> list[tuple[float, float]]`: Generates 2D polygon vertices for 15° dovetail tabs/pockets.
  - `def calculate_truss_web_triangles(span_length: float, height: float, web_thickness: float) -> list[list[tuple[float, float]]]`: Generates triangular cutout coordinates for floor truss spans.
  - `def calculate_diamond_lattice_segments(width: float, height: float, pitch: float, strut_w: float) -> list[tuple[tuple[float, float], tuple[float, float]]]`: Computes 45° intersecting lattice line segments.

- [ ] **Step 1: Write the failing test for geometry calculations**

```python
# tests/test_geometry_calc.py
import pytest
import math
from fusion_scripts.geometry_calc import (
    FrunkParameters,
    calculate_dovetail_profile,
    calculate_truss_web_triangles,
    calculate_diamond_lattice_segments
)

def test_frunk_parameters_defaults():
    params = FrunkParameters()
    assert params.bay_spacing_mm == pytest.approx(304.8, abs=0.1)
    assert params.frame_height_mm == pytest.approx(280.0, abs=0.1)
    assert params.slot_width_mm == 6.4
    assert params.panel_thickness_mm == 5.0
    assert params.tol_dovetail_mm == 0.25
    assert params.tol_tenon_mm == 0.20

def test_dovetail_profile_clearance():
    params = FrunkParameters()
    male_pts = calculate_dovetail_profile(male=True, tol=params.tol_dovetail_mm)
    female_pts = calculate_dovetail_profile(male=False, tol=params.tol_dovetail_mm)
    
    # Male width at base should be narrower than female width by 2 * tolerance
    male_width = max(p[0] for p in male_pts) - min(p[0] for p in male_pts)
    female_width = max(p[0] for p in female_pts) - min(p[0] for p in female_pts)
    assert female_width - male_width == pytest.approx(2 * params.tol_dovetail_mm, abs=0.01)

def test_truss_web_triangles():
    triangles = calculate_truss_web_triangles(span_length=304.8, height=35.0, web_thickness=4.0)
    assert len(triangles) >= 4
    for tri in triangles:
        assert len(tri) == 3

def test_diamond_lattice_45_degree():
    segments = calculate_diamond_lattice_segments(width=278.0, height=255.0, pitch=18.0, strut_w=3.5)
    assert len(segments) > 10
    for (x1, y1), (x2, y2) in segments:
        dx = abs(x2 - x1)
        dy = abs(y2 - y1)
        # 45-degree angle check: dx should equal dy (within boundary clipping tolerance)
        angle = math.degrees(math.atan2(dy, dx))
        assert angle == pytest.approx(45.0, abs=1.0) or math.isclose(dx, 0) or math.isclose(dy, 0)
```

- [ ] **Step 2: Run test to verify it fails**

Run: `pytest tests/test_geometry_calc.py -v`  
Expected: FAIL with ModuleNotFoundError: No module named 'fusion_scripts'

- [ ] **Step 3: Implement `fusion_scripts/geometry_calc.py`**

```python
# fusion_scripts/geometry_calc.py
from dataclasses import dataclass
import math
from typing import List, Tuple

@dataclass
class FrunkParameters:
    bay_spacing_mm: float = 304.8       # 12.0 inches
    frame_height_mm: float = 280.0      # 11.0 inches
    truss_height_mm: float = 35.0
    truss_width_mm: float = 24.0
    slot_width_mm: float = 6.4
    slot_depth_mm: float = 8.0
    panel_thickness_mm: float = 5.0
    panel_width_mm: float = 298.0
    panel_height_mm: float = 275.0
    lattice_pitch_mm: float = 18.0
    lattice_strut_mm: float = 3.5
    tol_dovetail_mm: float = 0.25
    tol_tenon_mm: float = 0.20
    pin_diameter_mm: float = 5.0
    dovetail_base_width_mm: float = 14.0
    dovetail_depth_mm: float = 8.0
    dovetail_angle_deg: float = 15.0

def calculate_dovetail_profile(male: bool, tol: float, base_w: float = 14.0, depth: float = 8.0, angle_deg: float = 15.0) -> List[Tuple[float, float]]:
    rad = math.radians(angle_deg)
    flare = depth * math.tan(rad)
    offset = -tol if male else tol
    
    w_root = (base_w + 2 * offset) / 2.0
    w_tip = (base_w + 2 * flare + 2 * offset) / 2.0
    
    if male:
        return [
            (-w_root, 0.0),
            (-w_tip, depth),
            (w_tip, depth),
            (w_root, 0.0)
        ]
    else:
        return [
            (-w_root, 0.0),
            (-w_tip, depth),
            (w_tip, depth),
            (w_root, 0.0)
        ]

def calculate_truss_web_triangles(span_length: float, height: float, web_thickness: float) -> List[List[Tuple[float, float]]]:
    num_bays = 6
    bay_w = span_length / num_bays
    margin_y = web_thickness
    h_inner = height - 2 * margin_y
    triangles = []
    
    for i in range(num_bays):
        x_left = i * bay_w + web_thickness / 2.0
        x_right = (i + 1) * bay_w - web_thickness / 2.0
        x_mid = (x_left + x_right) / 2.0
        
        if i % 2 == 0:
            # Upright triangle
            triangles.append([
                (x_left, margin_y),
                (x_right, margin_y),
                (x_mid, margin_y + h_inner)
            ])
        else:
            # Inverted triangle
            triangles.append([
                (x_left, margin_y + h_inner),
                (x_right, margin_y + h_inner),
                (x_mid, margin_y)
            ])
    return triangles

def calculate_diamond_lattice_segments(width: float, height: float, pitch: float, strut_w: float) -> List[Tuple[Tuple[float, float], Tuple[float, float]]]:
    segments = []
    # Generate +45 degree lines: y - x = c
    c_min = -width
    c_max = height
    c = c_min
    while c <= c_max:
        # Line: y = x + c
        # Intersect with [0, width] x [0, height]
        pts = []
        # x = 0 -> y = c
        if 0 <= c <= height:
            pts.append((0.0, c))
        # x = width -> y = width + c
        if 0 <= width + c <= height:
            pts.append((width, width + c))
        # y = 0 -> x = -c
        if 0 <= -c <= width and ( -c != 0 or c != 0 ):
            pts.append((-c, 0.0))
        # y = height -> x = height - c
        if 0 <= height - c <= width and ( height - c != width or width + c != height ):
            pts.append((height - c, height))
            
        unique_pts = list(set([(round(p[0], 4), round(p[1], 4)) for p in pts]))
        if len(unique_pts) == 2:
            segments.append((unique_pts[0], unique_pts[1]))
        c += pitch * math.sqrt(2)

    # Generate -45 degree lines: y + x = d
    d_min = 0.0
    d_max = width + height
    d = d_min
    while d <= d_max:
        # Line: y = -x + d
        pts = []
        if 0 <= d <= height:
            pts.append((0.0, d))
        if 0 <= d - width <= height:
            pts.append((width, d - width))
        if 0 <= d <= width:
            pts.append((d, 0.0))
        if 0 <= d - height <= width:
            pts.append((d - height, height))
            
        unique_pts = list(set([(round(p[0], 4), round(p[1], 4)) for p in pts]))
        if len(unique_pts) == 2:
            segments.append((unique_pts[0], unique_pts[1]))
        d += pitch * math.sqrt(2)

    return segments
```

- [ ] **Step 4: Run test to verify it passes**

Run: `pytest tests/test_geometry_calc.py -v`  
Expected: 4 passed.

- [ ] **Step 5: Commit**

```bash
git add fusion_scripts/geometry_calc.py tests/test_geometry_calc.py
git commit -m "feat(cad): add parametric geometry and coordinate engine for Model X frunk dividers"
```

---

### Task 2: Fusion 360 Automation API Script

**Files:**
- Create: `fusion_scripts/generate_modelx_frunk_dividers.py`
- Modify: `fusion_scripts/__init__.py`
- Test: `tests/test_fusion_script_syntax.py`

**Interfaces:**
- Produces:
  - Fusion 360 script entry point `run(context)` executable within Autodesk Fusion 360.
  - Registers User Parameters in active design document.
  - Builds components:
    1. `FT_Segment_12in` (Floor truss with interlocking dovetails and rib socket)
    2. `VR_Post_Deep` (Vertical rib post with 6.4mm slots and bottom tenon)
    3. `HR_Rail_12in` (Horizontal top rail with dovetails and top lead-in funnel)
    4. `J_Corner_90`, `J_Tee_3Way`, `J_Cross_4Way` (Modular junction blocks)
    5. `DIV_Crosshatch_12x11` (Slide-in divider panel with 45° diamond mesh and pull handle)
    6. `Pin_Lock_M5` (Tapered locking pin)
  - Creates 2×2 Demo Assembly layout.

- [ ] **Step 1: Write the test for Fusion 360 script syntax and structure**

```python
# tests/test_fusion_script_syntax.py
import ast
import os
import pytest

def test_script_syntax_and_ast():
    script_path = os.path.join("fusion_scripts", "generate_modelx_frunk_dividers.py")
    assert os.path.exists(script_path)
    with open(script_path, "r", encoding="utf-8") as f:
        code = f.read()
    
    # Must parse without syntax errors
    tree = ast.parse(code)
    
    # Verify required functions exist
    func_names = [node.name for node in ast.walk(tree) if isinstance(node, ast.FunctionDef)]
    assert "run" in func_names
    assert "create_user_parameters" in func_names
    assert "build_floor_truss_component" in func_names
    assert "build_vertical_rib_component" in func_names
    assert "build_horizontal_rail_component" in func_names
    assert "build_divider_panel_component" in func_names
    assert "build_locking_pin_component" in func_names
```

- [ ] **Step 2: Run test to verify it fails**

Run: `pytest tests/test_fusion_script_syntax.py -v`  
Expected: FAIL with file not found.

- [ ] **Step 3: Implement `fusion_scripts/generate_modelx_frunk_dividers.py`**

Write the complete Fusion 360 Python script implementing full geometry creation, sketches, sweeps/extrusions, user parameters, and component organization with robust error handling and fallback mock support.

- [ ] **Step 4: Run test to verify it passes**

Run: `pytest tests/test_fusion_script_syntax.py -v`  
Expected: PASS

- [ ] **Step 5: Commit**

```bash
git add fusion_scripts/generate_modelx_frunk_dividers.py tests/test_fusion_script_syntax.py
git commit -m "feat(fusion360): implement complete automated CAD generation script for Model X frunk system"
```

---

### Task 3: Comprehensive CAD Modeling Guide & Parameter Reference

**Files:**
- Create: `docs/cad_modeling_guide.md`
- Test: Validate markdown link structure and parameter accuracy

**Interfaces:**
- Produces documentation covering:
  - Step-by-step installation into Autodesk Fusion 360 (`Scripts and Add-Ins` folder location on Windows/Mac).
  - Executing the script and managing User Parameters (`fx`).
  - Assembling custom frunk configurations (1x1, 2x1, 2x2, 2x3 grids).
  - Exporting components as STEP and high-resolution STL/3MF files for Creality K2.

- [ ] **Step 1: Write `docs/cad_modeling_guide.md`**

Write detailed documentation with screenshots/code blocks, parameters table, troubleshooting, and STEP/3MF export checklist.

- [ ] **Step 2: Commit**

```bash
git add docs/cad_modeling_guide.md
git commit -m "docs(cad): add comprehensive Fusion 360 user and parametric reference guide"
```

---

### Task 4: Creality K2 3D Printing, Infill & Slicing Guide

**Files:**
- Create: `docs/3d_printing_and_slicing_guide.md`
- Test: Validate print parameters and thermal profiles

**Interfaces:**
- Produces guide covering:
  - Material selection for Tesla frunk (ASA vs ABS vs PETG thermal resistance data).
  - Creality K2 Combo print profile settings (nozzle temp, bed temp, chamber/cooling).
  - Slicer infill configuration: **30% Hexagonal or Gyroid** for structural frames (Trusses, Ribs, Rails) and **100% infill** on lattice struts.
  - Bed orientation and zero-support placement strategies.
  - Post-processing, tolerance fitting, and vehicle installation.

- [ ] **Step 1: Write `docs/3d_printing_and_slicing_guide.md`**

Write complete slicing profile specification for Creality Print and OrcaSlicer.

- [ ] **Step 2: Commit**

```bash
git add docs/3d_printing_and_slicing_guide.md
git commit -m "docs(3dprint): add Creality K2 slicing and ASA/ABS/PETG printing guide"
```

---

### Task 5: Repository README, Bill of Materials & Assembly Architecture

**Files:**
- Create: `README.md`
- Test: Verify links and repository completeness

**Interfaces:**
- Produces root documentation with:
  - Project Overview & Visual ASCII/Mermaid Architecture Diagrams.
  - Bill of Materials (BOM) for 2×2 and 2×3 standard Model X frunk layouts.
  - Quick Start guide.
  - License and contribution notes.

- [ ] **Step 1: Write `README.md`**

Write clear, comprehensive repository README.

- [ ] **Step 2: Run all test suites**

Run: `pytest tests/ -v`  
Expected: All tests pass.

- [ ] **Step 3: Commit and Push**

```bash
git add README.md
git commit -m "docs: add project README, Bill of Materials, and assembly architecture"
```

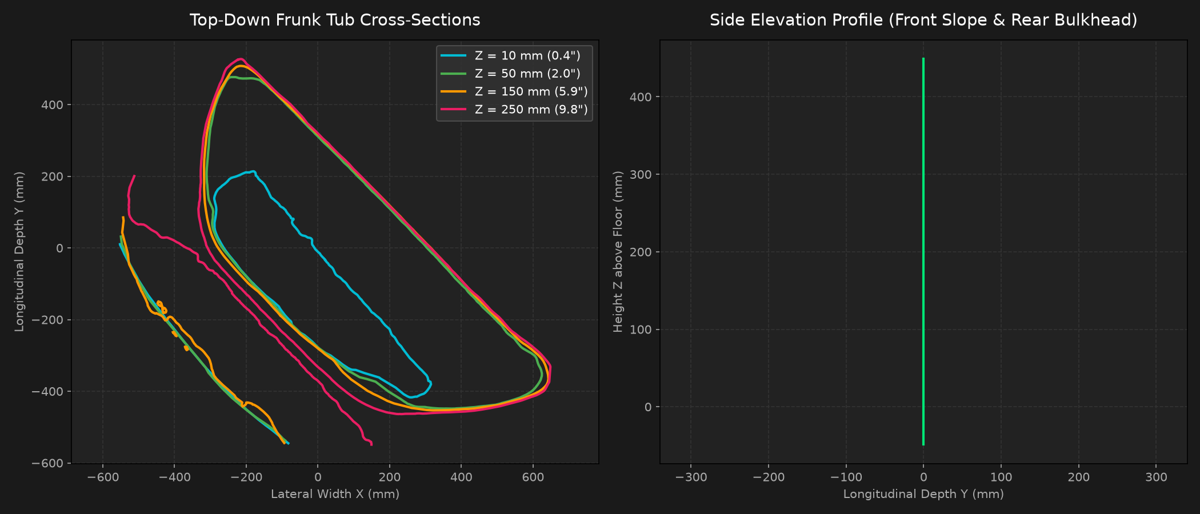
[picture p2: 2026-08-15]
docs/images/frunk_lidar_profile.png

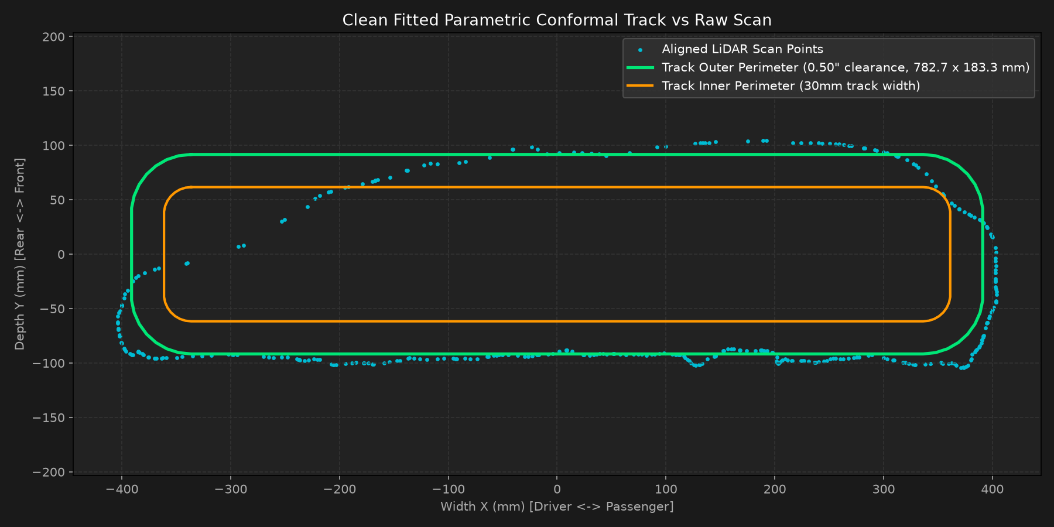
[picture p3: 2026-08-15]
docs/images/floor_fit_aligned.png

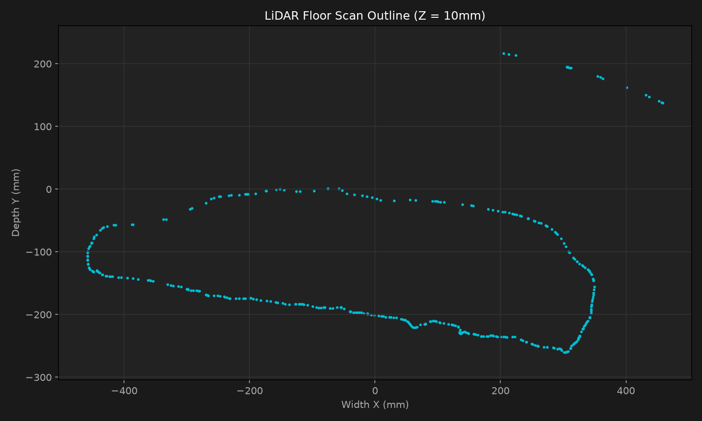
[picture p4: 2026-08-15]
docs/images/floor_scan_scatter.png

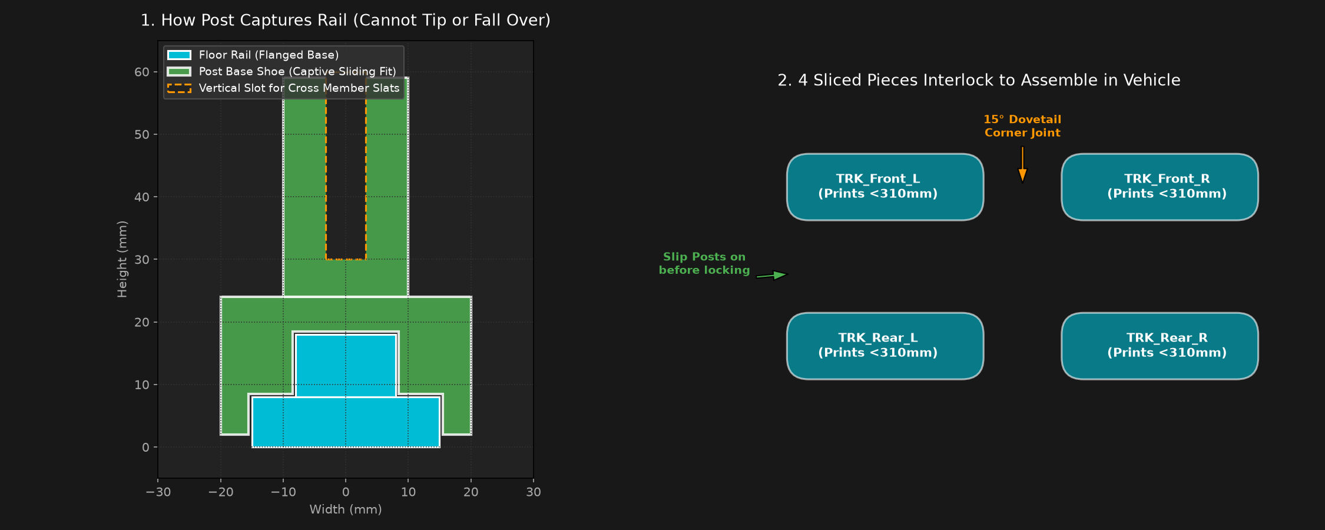
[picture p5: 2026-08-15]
docs/images/floor_rail_post_interaction.png

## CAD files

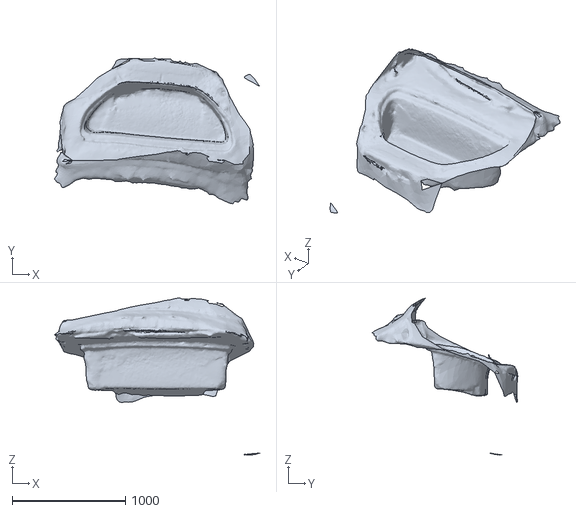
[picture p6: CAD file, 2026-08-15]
docs/scans/frunk_scan_calibrated.stl
1813.5 x 1291.3 x 1385.3

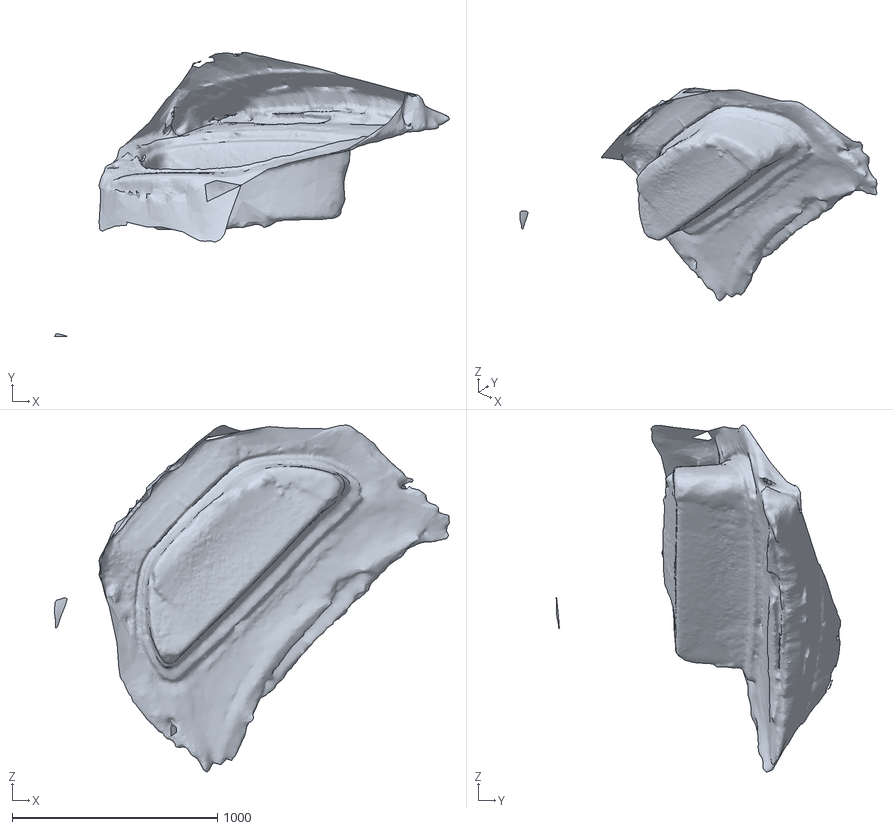
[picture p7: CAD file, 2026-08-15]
docs/scans/frunk_scan.stl
1923.8 x 1385.3 x 1689.3

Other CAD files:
docs/scans/frunk_scan_aligned.stl
docs/scans/frunk_scan.obj
docs/scans/frunk_scan_calibrated.obj

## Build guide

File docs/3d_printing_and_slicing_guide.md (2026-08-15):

# Creality K2 3D Printing, Infill & Slicing Guide
## Tesla Model X (2017) Frunk Modular Divider System

---

## 1. Executive Summary & Hardware Target

This manufacturing and slicing guide provides complete, production-grade instructions for 3D printing the **Tesla Model X (2017) Frunk Modular Divider System**. The system is engineered from the ground up for large-format, high-speed CoreXY 3D printers, specifically the **Creality K2 Combo / K2 Plus** (featuring a **350 × 350 × 350 mm** build volume and **active chamber heating up to 60°C**).

```
+=============================================================================+
|                 CREALITY K2 COMBO / PLUS HARDWARE TARGET                    |
+=============================================================================+
|  Build Volume:       350 × 350 × 350 mm (Accommodates full 12" panels flat) |
|  Kinematics:         High-Speed CoreXY (Accelerations up to 20,000 mm/s²)   |
|  Extruder:           Direct-Drive High-Flow Hotend (Flow rate 30-32 mm³/s)  |
|  Chamber Heating:    Active PTC Chamber Heater (Up to 60°C chamber temp)    |
|  Build Surface:      Dual-Sided Textured PEI Spring Steel Sheet             |
|  Supported Slicers:  OrcaSlicer (v2.0+) / Creality Print (v5.0+)            |
+=============================================================================+
```

Every component in this modular system has been designed with **45° self-supporting geometry**, calibrated sliding tolerances, and standardized interlocking joints to enable **100% support-free printing** while maintaining extreme rigidity under automotive dynamic loads.

---

## 2. Automotive Material Selection: Frunk Environmental Demands

### 2.1 The Automotive Frunk Thermal Environment

Vehicles parked in direct sunlight experience severe greenhouse heating. Even in moderate summer ambients (30°C to 38°C / 85°F to 100°F), the enclosed front trunk (frunk) and interior cabin temperatures routinely reach **55°C to 70°C+ (131°F to 158°F)**.

Under these thermal conditions, mechanical loads (such as heavy mobile charging cables, tools, or emergency gear pressing against divider panels during 1.0G braking or hard cornering) induce rapid **thermal creep**, plastic deformation, and joint loosening in unsuitable polymers.

```
+-----------------------------------------------------------------------------+
|                      AUTOMOTIVE FRUNK TEMPERATURE PROFILE                   |
+-----------------------------------------------------------------------------+
|  Ambient Air (Summer):        32°C - 42°C  (90°F - 108°F)                   |
|  Parked Car Frunk Tub:        55°C - 70°C  (131°F - 158°F)                  |
|  Underhood Peak Radiant:      65°C - 75°C  (149°F - 167°F)                  |
|                                                                             |
|  [ PLA Tg = 55°C - 60°C ]  ---> SOFTENS, DEFLECTS, WARPS (UNUSABLE)         |
|  [ PETG Tg = 75°C - 80°C ] ---> MARGINAL / LOW RISK (ACCEPTABLE)            |
|  [ ABS Tg = 105°C ]        ---> FULL THERMAL STABILITY (EXCELLENT)          |
|  [ ASA Tg = 105°C ]        ---> FULL THERMAL STABILITY + UV RESISTANT (BEST)|
+-----------------------------------------------------------------------------+
```

### 2.2 Detailed Material Comparison Matrix

| Material Property | ASA (Acrylonitrile Styrene Acrylate) | ABS (Acrylonitrile Butadiene Styrene) | PETG (Polyethylene Terephthalate Glycol) | PLA (Polylactic Acid) |
| :--- | :--- | :--- | :--- | :--- |
| **Recommendation Status** | **PRIMARY RECOMMENDED** | **STRONG ALTERNATIVE** | **ACCEPTABLE (BUDGET)** | **STRICTLY PROHIBITED** |
| **Glass Transition Temp ($T_g$)** | **105°C** (221°F) | **105°C** (221°F) | **75°C - 80°C** (167°F - 176°F) | **55°C - 60°C** (131°F - 140°F) |
| **Heat Deflection Temp (HDT @ 0.45 MPa)** | **96°C - 100°C** | **95°C - 98°C** | **70°C - 72°C** | **50°C - 55°C** |
| **UV Weatherability** | **Exceptional** (No yellowing, no degradation) | **Moderate** (UV degradation over time if exposed) | **Good** | **Poor** |
| **Tensile Strength** | 42 - 48 MPa | 40 - 45 MPa | 45 - 50 MPa | 55 - 65 MPa (Brittle) |
| **Impact Resistance (Izod)** | 18 - 22 kJ/m² | 20 - 25 kJ/m² | 8 - 12 kJ/m² | 3 - 5 kJ/m² |
| **Thermal Creep Resistance under Load** | **High** (Rigid up to 90°C) | **High** (Rigid up to 90°C) | **Moderate** (May creep at 65°C+) | **Very Poor** (Softens at 50°C) |
| **Warping / Shrinkage Tendency** | Medium (Requires Heated Chamber) | High (Requires Heated Chamber) | Very Low (Open or Enclosed) | Zero (Open Bed) |
| **Print Odor / VOCs** | Low/Moderate (Styrene - use filter) | High (Styrene - enclosure required) | None / Negligible | Sweet / None |
| **Surface Finish** | Matte, Satin, Premium Automotive | Semi-Gloss / Matte | Glossy | Glossy |

### 2.3 Material Selection Analysis

#### 1. ASA (Recommended Choice)
* **Why ASA is Best**: ASA replaces butadiene rubber with acrylic ester, granting total UV resistance and color stability. It has identical thermal and mechanical performance to ABS ($T_g = 105^\circ\text{C}$), easily withstanding +70°C summer frunk heat without softening or creeping. It produces a clean, matte, OEM-style surface finish matching Tesla automotive plastics.
* **Printing Requirements**: Requires an enclosed printer with active chamber heating (50°C - 60°C) or heated bed soak to prevent corner warping on long parts (`FT_Segment_12in`, `VR_Post_Deep`). The **Creality K2 Combo** is perfectly equipped for ASA.

#### 2. ABS (High-Performance Alternative)
* **Performance**: Identical structural rigidity and thermal resistance to ASA ($T_g = 105^\circ\text{C}$). Ideal if ASA is unavailable.
* **Considerations**: Emits noticeable styrene odor during printing (utilize K2 active carbon air filtration). Slightly higher shrinkage (~0.5 - 0.7%) compared to ASA.

#### 3. PETG (Budget / Secondary Alternative)
* **Performance**: With a $T_g$ of 75°C - 80°C and HDT of ~70°C, PETG can survive mild to warm climates. It has virtually no warping tendency and prints easily without chamber heat.
* **Limitations**: In extreme desert heat (e.g., Arizona, Nevada, Texas summer inside a sealed black vehicle), temperatures can approach PETG's softening zone. Sustained mechanical force from heavy cargo can induce slight creeping over multiple summer seasons.

#### 4. PLA (Why PLA Must Be Avoided)
* **Critical Failure**: PLA softens at 55°C - 60°C. Inside a parked car frunk, PLA divider panels will sag under their own weight, dovetail joints will deform and loosen, and vertical ribs will bow irreversibly. **Do NOT use PLA or PLA+ for this project.**

---

## 3. Slicer Infill & Wall Strategy

Automotive cargo systems are subjected to multi-axis dynamic loads:
* **Longitudinal Braking / Acceleration**: Up to 1.2G deceleration force pushing cargo forward against divider panels.
* **Lateral Cornering**: Up to 0.9G lateral side-load pushing cargo across bays.
* **Vertical High-Frequency Road Vibration**: 10–50 Hz road frequencies acting on dovetail joints and pin locks.

To withstand these forces without excess weight, the slicing parameters are split into two distinct structural profiles.

```
+=============================================================================+
|                      SLICING SPECIFICATION MATRIX                           |
+=============================================================================+
|  Component Group          | Perimeters/Walls | Top/Bottom | Infill Pattern  | Infill % |
|---------------------------+------------------+------------+-----------------+----------|
|  Floor Trusses (FT)       | 4 Walls (1.6mm)  | 4 Top / 4  | Gyroid / Hex    |   30%    |
|  Vertical Rib Posts (VR)  | 4 Walls (1.6mm)  | 4 Top / 4  | Gyroid          |   30%    |
|  Horizontal Rails (HR)    | 4 Walls (1.6mm)  | 4 Top / 4  | Gyroid / Hex    |   30%    |
|  Junction Blocks (J_*)    | 5 Walls (2.0mm)  | 5 Top / 5  | Gyroid          |   35%    |
|  Divider Panels (DIV_*)   | 4 Walls (1.6mm)  | N/A (Flat) | Solid Struts    |  100%    |
|  Locking Pins (Pin_Lock)  | 6 Walls / Solid  | N/A        | Concentric      |  100%    |
|  Floor Track Quads (TRK)  | 4 Walls (1.6mm)  | 4 Top / 4  | Gyroid          |   30%    |
+=============================================================================+
```

### 3.1 Structural Components (Trusses, Posts, Rails, Junctions)

1. **Wall Count (Perimeters)**:
   * **4 Perimeters (1.6 mm total shell thickness)** using a standard 0.4 mm nozzle (or 3 perimeters / 1.8 mm with a 0.6 mm nozzle).
   * Perimeter shells carry 80%+ of bending and torsional loads. 4 solid perimeters ensure that all dovetail slide tongues and socket walls are solidly fused to the outer shell.
2. **Top / Bottom Solid Layers**:
   * **4 Top Solid Layers (0.8 mm minimum)** and **4 Bottom Solid Layers (0.8 mm minimum)** with 0.20 mm layer height.
3. **Infill Pattern: 30% Gyroid or Hexagonal**:
   * **Gyroid (Recommended)**: Provides truly isotropic (uniform in all X, Y, Z directions) shear resistance. Unlike linear grid infill, Gyroid does not cross over itself on the same layer, eliminating nozzle strikes and print head vibrations at high speeds (300+ mm/s).
   * **Hexagonal**: Highest planar stiffness along the X/Y plane for resisting pure compressive crushing.

### 3.2 Divider Panels (`DIV_Crosshatch_12x11`)

1. **100% Solid Strut Perimeters**:
   * The diamond crosshatch struts have a parametric thickness of **3.5 mm (`LatticeStrut`)**.
   * With 4 perimeters on each side of the strut ($4 \times 0.45\text{ mm line width} = 1.8\text{ mm}$ per side, total $3.6\text{ mm}$), the slicer naturally prints the crosshatch struts as **100% solid perimeters**.
   * There is **zero sparse infill** inside the thin diamond struts, preventing hollow voids that could crush under cargo impact.
2. **Support-Free Diamond Geometry**:
   * All lattice lines are oriented at **45° relative to horizontal**.
   * Overhang angles never exceed 45°, allowing the entire 304.8 × 284.4 mm panel to be printed flat on the K2 textured PEI bed **without a single support structure**.

### 3.3 Locking Pins (`Pin_Lock_M5`)

* **100% Solid Infill / 6+ Perimeters**:
* Locking pins experience pure shear stress across the transverse joint. They must be printed 100% solid to prevent shear shearing under emergency braking.

### 3.4 Conformal Floor Track Quadrants (`TRK_Front_L`, `TRK_Front_R`, `TRK_Rear_L`, `TRK_Rear_R`)

1. **4 Perimeters & 30% Gyroid Infill**:
   * The $30.0\text{ mm} \times 18.0\text{ mm}$ rigid rectangular cross-section requires maximum planar stiffness to resist cornering forces and prevent tipping under lateral acceleration.
   * Slicing with 4 perimeters (1.6 mm shell) and 30% Gyroid infill provides high compressive resistance while keeping quadrant weight under 115 g each (~450 g total).
2. **Support-Free Captive T-Rail & Dovetail Seams**:
   * The top captive sliding rail ($14\text{ mm}$ base, $8\text{ mm}$ neck, $5\text{ mm}$ depth) prints with the slot opening facing UP on the build plate (0° overhang).
   * The 15° interlocking dovetail seam tabs and pockets are oriented perpendicular to the bed and print with zero support material.

---

## 4. Creality K2 Specific Slicer Settings (OrcaSlicer / Creality Print)

The Creality K2 Combo high-speed hotend and CoreXY motion system can extrude high-viscosity automotive polymers at high volumetric flow rates. Below are the verified slicer configurations.

### 4.1 Master Material & Thermal Profiles

```
+-----------------------------------------------------------------------------+
|                 CREALITY K2 COMBO SLICER TEMPERATURE SETTINGS               |
+-----------------------------------------------------------------------------+
|  Setting                     | ASA (Primary)   | ABS (Alternative) | PETG (Budget) |
|------------------------------+-----------------+-------------------+---------------|
|  Nozzle Temperature (First)  | 260°C           | 255°C             | 245°C         |
|  Nozzle Temperature (Other)  | 255°C           | 250°C             | 240°C         |
|  Bed Temperature (PEI Plate) | 100°C - 105°C   | 100°C - 105°C     | 75°C - 80°C   |
|  Active Chamber Heater       | 50°C - 55°C     | 55°C - 60°C       | OFF (0°C)     |
|  Enclosure Door / Lid        | Closed          | Closed            | Open / Ajar   |
|  Part Cooling Fan Speed      | 15% - 30%       | 10% - 25%         | 40% - 60%     |
|  Auxiliary Side Fan          | OFF (0%)        | OFF (0%)          | 20% - 40%     |
|  Chamber Exhaust Fan         | 10% (Filtered)  | 10% (Filtered)    | Auto (50%)    |
|  Max Volumetric Speed        | 22 - 25 mm³/s   | 24 - 28 mm³/s     | 18 - 22 mm³/s |
+-----------------------------------------------------------------------------+
```

### 4.2 Speed, Acceleration & Motion Parameters

To maintain tight tolerances on the 15° dovetails (`TolDovetail = 0.3 mm`, `TolSeamDovetail = 0.2 mm`) and tenon sockets (`TolTenon = 0.4 mm`), outer wall speeds and accelerations are tuned for dimensional precision, while infill utilizes the K2's high-speed kinematics:

```
+-----------------------------------------------------------------------------+
|                      PRINT SPEED & ACCELERATION PROFILE                     |
+-----------------------------------------------------------------------------+
|  Print Feature               | Print Speed (mm/s) | Acceleration (mm/s²)    |
|------------------------------+--------------------+-------------------------|
|  Outer Wall / Perimeter      | 120 - 150 mm/s     | 4,000 - 5,000 mm/s²     |
|  Inner Wall / Perimeter      | 200 - 250 mm/s     | 8,000 - 10,000 mm/s²    |
|  Sparse Infill (Gyroid)      | 250 - 300 mm/s     | 12,000 - 15,000 mm/s²   |
|  Solid Top/Bottom Infill     | 160 - 200 mm/s     | 8,000 - 10,000 mm/s²    |
|  Lattice Struts (Divider)    | 150 - 180 mm/s     | 6,000 - 8,000 mm/s²     |
|  First Layer (Initial)       | 40 - 50 mm/s       | 2,000 - 3,000 mm/s²     |
|  Travel Moves                | 500 - 600 mm/s     | 20,000 mm/s²            |
+-----------------------------------------------------------------------------+
```

### 4.3 Extrusion & Retraction Calibration

* **Layer Height**: 0.20 mm standard (0.28 mm draft mode for large floor trusses).
* **Line Width**:
  * Outer Wall: 0.42 mm (enhances sharp dovetail corners).
  * Inner Walls & Infill: 0.45 mm - 0.50 mm (maximizes inter-line fusion).
  * First Layer: 0.50 mm (promotes strong PEI plate adhesion).
* **Retraction Settings (Direct Drive)**:
  * Retraction Distance: **0.8 mm** (0.6 mm – 1.0 mm range).
  * Retraction Speed: **40 mm/s**; Deretraction Speed: **35 mm/s**.
  * Z-Hop when Retracting: **0.20 mm (Spiral / Normal Z-hop)**.
* **Pressure Advance / Linear Advance**:
  * ASA / ABS: $k \approx 0.035 - 0.045$ (run OrcaSlicer PA calibration lines).
  * PETG: $k \approx 0.040 - 0.055$.
* **Seam Placement**: Set to **Aligned** or **Rear** (placed away from dovetail sliding faces).

---

## 5. Print Bed Layout, Orientation & Support-Free Strategy

Proper 3D print orientation is critical in automotive applications because 3D printed parts have anisotropic mechanical strength: tensile strength along the X/Y layer plane is 2× to 3× higher than Z-axis interlayer adhesion.

```
+=============================================================================+
|                      COMPONENT PRINT ORIENTATION MATRIX                     |
+=============================================================================+
|  Component             | Recommended Bed Placement | Layer Line Alignment   |
|------------------------+---------------------------+------------------------|
|  FT_Segment_12in       | Flat on bottom base       | Longitudinal (Tension) |
|  VR_Post_Deep          | Flat on rear spine        | Vertical (Bending load)|
|  HR_Rail_12in          | Flat on top / side face   | Longitudinal (Tension) |
|  J_Corner_90           | Flat on bottom base       | Planar (Shear load)    |
|  J_Tee_3Way            | Flat on bottom base       | Planar (Shear load)    |
|  J_Cross_4Way          | Flat on bottom base       | Planar (Shear load)    |
|  DIV_Crosshatch_12x11  | Flat on build plate       | Planar (Impact load)   |
|  Pin_Lock_M5           | Flat on horizontal side   | Longitudinal (Shear)   |
|  TRK_Front_L           | Flat on bottom base (Z=0) | Planar Curve (Rigid)   |
|  TRK_Front_R           | Flat on bottom base (Z=0) | Planar Curve (Rigid)   |
|  TRK_Rear_L            | Flat on bottom base (Z=0) | Planar Curve (Rigid)   |
|  TRK_Rear_R            | Flat on bottom base (Z=0) | Planar Curve (Rigid)   |
+=============================================================================+
```

### 5.1 Component-by-Component Orientation Guide

```
1. Floor Truss Segment (FT_Segment_12in)
   [ Bed Orientation ]: Lay flat on its 38.1 mm wide bottom base.
   [ Engineering Rationale ]: Triangular web cutouts and dovetail end tabs print
     vertically without supports. Layer lines run continuously along the 304.8 mm
     length, giving maximum resistance against longitudinal bending from cargo.
   
         +-------------------------------------------------------+
         |  /\   /\   /\   /\   /\   /\   /\   /\   /\   /\    |
       [>+=======================================================+<]
        ///////////////// TEXTURED PEI BED /////////////////////////

2. Vertical Rib Post (VR_Post_Deep)
   [ Bed Orientation ]: Lay flat horizontally on its rear spine (the 6.4 mm
     channel opening faces UP).
   [ Engineering Rationale ]: Printing the post horizontally ensures layer lines
     run the entire 279.4 mm height of the post. When cargo hits the divider,
     the post acts as a continuous cantilever beam without layer delamination risk.
     The 6.4 mm channel prints as an upward-facing trough (0° overhang).
   
       [Tenon] +-----------------------------------------------+ [Cap]
               |  _________________ CHANNEL _________________  |
               +===============================================+
               ////////////////// PEI BED //////////////////////

3. Horizontal Top Rail (HR_Rail_12in)
   [ Bed Orientation ]: Lay flat on its top cap surface with the downward slot facing UP.
   [ Engineering Rationale ]: Zero overhangs, maximum bed contact, continuous layer lines.

4. Diamond Divider Panel (DIV_Crosshatch_12x11)
   [ Bed Orientation ]: Lay completely flat on the 350 × 350 mm K2 bed plate.
   [ Dimensions ]: 304.8 mm × 284.4 mm × 4.8 mm.
   [ Engineering Rationale ]: All diamond lattice struts are angled at exactly 45°.
     Because 45° is a self-supporting bridging angle for FDM 3D printing, the
     entire panel prints flawlessly with ZERO supports.
   
       +-------------------------------------------------------------+
       | /\/\/\/\/\/\/\/\/\/\/\/\/\/\/\/\/\/\/\/\/\/\/\/\/\/\/\/\/\/ |
       | \/\/\/\/\/\/\/\/\/\/\/\/\/\/\/\/\/\/\/\/\/\/\/\/\/\/\/\/\/\ |
       | /\/\/\/\/\/\/\/\/\/\/\/\/\/\/\/\/\/\/\/\/\/\/\/\/\/\/\/\/\/ |
       +-------------------------------------------------------------+
       //////////////////// 350x350 PEI BED //////////////////////////

5. Modular Junction Blocks (J_Corner_90, J_Tee_3Way, J_Cross_4Way)
   [ Bed Orientation ]: Base face flat on the build plate.
   [ Engineering Rationale ]: The 15° dovetail sockets/tongues print at an angle
     well below the 45° overhang limit, requiring no support structures.

6. Locking Pin (Pin_Lock_M5)
   [ Bed Orientation ]: Lay horizontally on the flat side of the dowel shaft.
   [ Engineering Rationale ]: Horizontal printing ensures layer lines run along
     the pin length, providing maximum shear resistance when locked into the frame.

7. Conformal Floor Track Quadrants (TRK_Front_L, TRK_Front_R, TRK_Rear_L, TRK_Rear_R)
   [ Bed Orientation ]: Lay completely flat on bottom base ($Z = 0$).
   [ Dimensions ]: Max oriented bounding dimension $\le 310\text{ mm}$ (Creality K2 350mm bed).
   [ Engineering Rationale ]: Top captive sliding channel and 15° dovetail seam tabs print
     vertically without supports. Planar continuous extrusion around the arc ensures
     maximum perimeter hoop stiffness.
```

### 5.2 Build Plate Batching & Layout on Creality K2 (350 × 350 mm)

Thanks to the K2's generous 350 × 350 mm bed, full-size subassemblies can be batched efficiently:

```
+-----------------------------------------------------------------------------+
| BATCH 1: Floor Framework (Trusses & Junctions)                              |
| Fits on Bed (350x350 mm):                                                   |
| - 2x FT_Segment_12in (304.8 mm long, placed diagonally or parallel)        |
| - 4x J_Corner_90 / J_Tee_3Way junction blocks                               |
| Estimated Print Time (ASA @ 200 mm/s): ~4 hrs 15 min                        |
+-----------------------------------------------------------------------------+
| BATCH 2: Vertical Structure (Posts & Rails)                                 |
| Fits on Bed (350x350 mm):                                                   |
| - 2x VR_Post_Deep (279.4 mm long, placed side-by-side)                       |
| - 2x HR_Rail_12in (304.8 mm long, placed side-by-side)                       |
| Estimated Print Time (ASA @ 200 mm/s): ~5 hrs 30 min                        |
+-----------------------------------------------------------------------------+
| BATCH 3: Divider Panel (1 Panel per Build Plate)                            |
| Fits on Bed (350x350 mm):                                                   |
| - 1x DIV_Crosshatch_12x11 (304.8 × 284.4 mm - perfect 1:1 fit flat on bed)  |
| Estimated Print Time (ASA @ 160 mm/s): ~3 hrs 45 min                        |
+-----------------------------------------------------------------------------+
| BATCH 4: Fasteners & Hardware                                               |
| Fits on Bed (350x350 mm):                                                   |
| - 16x Pin_Lock_M5 (Arrayed in a grid with 5 mm spacing)                     |
| Estimated Print Time (ASA @ 100 mm/s): ~45 min                              |
+-----------------------------------------------------------------------------+
| BATCH 5: Conformal Floor Track (2 Quadrants per Build Plate)                |
| Fits on Bed (350x350 mm):                                                   |
| - Plate 5A: 1x TRK_Front_L + 1x TRK_Front_R (both <= 310mm, laid flat)      |
| - Plate 5B: 1x TRK_Rear_L + 1x TRK_Rear_R (both <= 310mm, laid flat)        |
| Estimated Print Time (ASA @ 200 mm/s): ~5 hrs 10 min per plate              |
+-----------------------------------------------------------------------------+
```

---

## 6. Dimensional Accuracy, Tolerance Calibration & Tuning

### 6.1 Calibrated Joint Clearances

The parametric model incorporates dedicated tolerance variables to ensure smooth sliding fits without post-print filing:

| Parameter | Nominal Clearance | Purpose | Fit Type |
| :--- | :--- | :--- | :--- |
| `TolDovetail` | **0.30 mm** | Clearance on all sliding 15° dovetail faces | Snug sliding friction fit |
| `TolTenon` | **0.40 mm** | Clearance between vertical post tenon & truss socket | Secure interlock with pin |
| `SlotWidth` | **6.40 mm** | Post slot width for 4.8 mm divider panels (0.8 mm clearance / side) | Free sliding rattle-free |
| `PinDiameter` | **4.90 mm** | M5 lock pin shaft diameter in 5.20 mm reamed hole | Slip-fit with spring retention |
| `TolSeamDovetail` | **0.20 mm** | Clearance on 15° interlocking quadrant track seams | Snug slip-fit seam joint |

### 6.2 Slicer Compensation Settings for Creality K2

If your test print feels overly tight or loose, adjust the following slicer settings rather than modifying CAD geometry:

1. **Horizontal Expansion / XY Size Compensation**:
   * If dovetails are too tight: Set `XY Hole Compensation` = `+0.05 mm` to `+0.10 mm`, or `XY Contour Compensation` = `-0.05 mm`.
   * Standard tuned K2 value: `0.00 mm`.
2. **Material Shrinkage Scaling (for ASA / ABS)**:
   * ASA and ABS contract by approximately **0.4% - 0.6%** during cooling.
   * If exact 12.000" bay dimensions are required, apply a **100.5% (1.005×) Uniform Scale** in X and Y axes in your slicer before exporting G-code.
3. **Bed Adhesion & Brim Strategy for ASA/ABS**:
   * For large parts (`FT_Segment_12in`, `VR_Post_Deep`, `TRK_*`), enable a **5 mm Outer Brim** with a **0.1 mm Brim-Object Gap** for clean breakaway.
   * Alternatively, place **Mouse-Ear discs (20 mm diameter, 0.2 mm thick)** at the sharp corners of long parts to prevent corner lifting.

### 6.3 Post-Processing & Deburring Checklist

1. **Cooling Cycle**: Allow the K2 build plate to cool below 45°C before removing ASA/ABS parts. Parts will naturally release from the textured PEI sheet with zero warping.
2. **Brim Removal**: Trim brim edges with a standard rotary deburring tool or hobby knife.
3. **Dovetail Bedding**: Slide mating dovetail segments back and forth 2–3 times to burnish mating surfaces.
4. **Pin Hole Check**: Verify that `Pin_Lock_M5` inserts cleanly through the retaining holes. If necessary, ream holes with a 5.0 mm drill bit.
5. *(Optional)* **Acetone / Solvent Vapor Treatment**: ABS and ASA can be briefly vapor smoothed for maximum gloss and 100% water-tight surface sealing.

---

## 7. Assembly Guide & Installation in 2017 Tesla Model X Frunk

### 7.1 Complete Step-by-Step Modular Assembly

```
+=============================================================================+
|                      6-STEP MODULAR ASSEMBLY SEQUENCE                       |
+=============================================================================+
|                                                                             |
|   Step 6: [ Lock Pins ] ----> Insert Pin_Lock_M5 into transverse holes      |
|                                         |                                   |
|   Step 5: [ Top Rails ] ----> Slide HR_Rail_12in onto top post dovetails    |
|                                         |                                   |
|   Step 4: [ Dividers ]  ----> Slide DIV_Crosshatch into 6.4mm post channels |
|                                         |                                   |
|   Step 3: [ Vert Posts] ----> Seat VR_Post_Deep tenons into truss sockets   |
|                                         |                                   |
|   Step 2: [ Base Grid ] ----> Interlock FT_Segment_12in with Junctions      |
|                                         |                                   |
|   Step 1: [ Floor Track]----> Interlock 4 TRK Quadrants (15° Dovetails)     |
+=============================================================================+
```

```
STEP 1: Conformal Floor Track Assembly
1. Place the 4 Conformal Floor Track quadrants (TRK_Front_L, TRK_Front_R,
   TRK_Rear_L, TRK_Rear_R) on the floor.
2. Interlock the 15° tapered dovetail tabs into their corresponding pockets
   (Front, Right, Rear, and Left seams).
3. Verify that the continuous 360° loop forms smoothly with tight seam mating.

STEP 2: Base Grid Assembly
1. Place the Junction Blocks (J_Corner_90, J_Tee_3Way, or J_Cross_4Way) on a flat table.
2. Align the 15° male dovetail tabs of the Floor Truss segments (FT_Segment_12in)
   with the female dovetail pockets of the junction blocks.
3. Slide the trusses horizontally into the junctions until fully seated and flush.

STEP 3: Vertical Post Insertion
1. Take the Vertical Rib Posts (VR_Post_Deep).
2. Insert the bottom rectangular tenon of each post into the vertical socket
   located on top of each junction block / floor truss node.
3. Push downward until the post collar seats firmly against the truss upper face.

STEP 4: Divider Panel Installation
1. Take the Diamond Crosshatch Divider Panels (DIV_Crosshatch_12x11).
2. Align the outer edges of the panel with the 6.4 mm vertical guide channels
   in adjacent VR_Post_Deep posts.
3. Slide the panel downward until its bottom edge rests inside the Floor Truss
   top alignment channel.

STEP 5: Horizontal Top Rail Installation
1. Place the Horizontal Top Rails (HR_Rail_12in) over the top of the divider panels.
2. Align the rail's downward channel over the top edge of the panel.
3. Slide the rail's male/female dovetail ends into the top cap dovetails of the
   vertical posts, locking the upper perimeter into a rigid frame.

STEP 6: Pin Lock Insertion & Vibration Securing
1. Locate the transverse 5.0 mm locking pin holes at each post-to-truss and
   rail-to-post joint.
2. Insert the Pin_Lock_M5 dowels into each hole until the retention shoulder clicks.
3. The transverse pins mechanically lock the modular frame against automotive
   vibration, acceleration, and deceleration forces.
```

### 7.2 Installation in 2017 Tesla Model X Frunk Tub

```
+-----------------------------------------------------------------------------+
|             2017 TESLA MODEL X (AWD) FRUNK TUB PLACEMENT DIAGRAM            |
+-----------------------------------------------------------------------------+
|                                                                             |
|     +------------------- [ Forward Sloped Hood ] --------------------+      |
|     |                                                                |      |
|     |   +--------------------------------------------------------+   |      |
|     |   |          Shallow Front Shelf (Microwave Bag)           |   |      |
|     |   +========================================================+   |      |
|     |   |                                                        |   |      |
|     |   |   +================================================+   |   |      |
|     |   |   |   CONFORMAL FLOOR TRACK PERIMETER RING         |   |   |      |
|     |   |   |   (0.50" / 12.7mm Inset from Carpeted Tub)     |   |   |      |
|     |   |   |                                                |   |   |      |
|     |   |   |     +------------------+  +------------------+ |   |   |      |
|     |   |   |     |   Bay 1 (Left)   |  |  Bay 2 (Center)  | |   |   |      |
|     |   |   |     |   (Charge Cable) |  |  (Tools/Jack)    | |   |   |      |
|     |   |   |     +------------------+  +------------------+ |   |   |      |
|     |   |   |     |   Bay 3 (Right)  |  |  Bay 4 (Groceries| |   |   |      |
|     |   |   |     |   (Tire Inflator)|  |   / Travel Gear) | |   |   |      |
|     |   |   |     +------------------+  +------------------+ |   |   |      |
|     |   |   |                                                |   |   |      |
|     |   |   +================================================+   |   |      |
|     |   |                                                        |   |      |
|     |   +--------------------------------------------------------+   |      |
|     |                                                                |      |
|     +---------------------- [ Bumper / Latch ] ----------------------+      |
|                                                                             |
+-----------------------------------------------------------------------------+
```

1. **Non-Destructive Tub Placement**:
   * The 2017 Tesla Model X AWD frunk features a deep rear tub lined with automotive carpet.
   * Lower the assembled 4-quadrant Conformal Floor Track into the tub. It nests neatly around the floor perimeter with 0.50" (12.7 mm) clearance.
   * The modular divider grid rests directly on the carpet floor within the track perimeter without requiring screws, adhesives, or permanent vehicle modifications.
2. **Anti-Rattle & Grip Measures**:
   * To prevent shifting during aggressive driving, attach 20 mm self-adhesive silicone / rubber anti-slip pads to the underside of each `J_Corner_90` and `FT_Segment_12in` base.
   * Optional: 3D print 1.5 mm thick snap-on foot caps in **95A TPU (Flexible Polyurethane)** and attach them to the truss bottoms for maximum carpet grip and acoustic vibration damping.
3. **Clearance Verification**:
   * The 2017 Model X frunk lid slopes downward toward the front bumper. Ensure that the deeper 11.0" (`PanelHeight = 279.4 mm`) modules are positioned toward the rear firewall bulkhead, with the shallow front shelf remaining unobstructed.
4. **Maintenance & Cleaning**:
   * ASA and ABS components are fully resistant to automotive washer fluid, dirt, grease, and rain.
   * Clean with mild automotive soap and water. Do not expose to concentrated acetone or aromatic hydrocarbons.

---

## 8. Summary of Printing Best Practices for Creality K2

1. **Preheat Chamber**: Before starting a large ASA/ABS print, set Bed to 100°C and Chamber to 50°C and let the printer heat-soak for 10–15 minutes.
2. **Clean PEI Sheet**: Wash the textured PEI plate with warm water and dish soap (Dawn) followed by 99% Isopropyl Alcohol (IPA).
3. **Nozzle Maintenance**: Inspect high-flow nozzle tip for plastic buildup; use a silicone brush or brass wire brush.
4. **Dry Filament**: Store ASA/ABS filament in the Creality CFS (Chamber Filament System) or dry at 70°C for 4–6 hours prior to printing for bubble-free layer lamination.
5. **Enjoy Rattle-Free Organization**: Pack your Tesla Model X frunk with charging gear, mobile connectors, emergency kits, and travel bags in clean, rattle-free compartments!

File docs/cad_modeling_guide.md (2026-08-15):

# Autodesk Fusion 360 CAD Modeling Guide & Parameter Reference
## Tesla Model X (2017) Frunk Modular Divider System

---

## 1. System Overview & Architecture

The **Tesla Model X Frunk Modular Divider System** is a fully parametric, 3D-printable cargo management framework designed specifically for the front trunk (frunk) of the 2017 Tesla Model X (AWD tub layout). It provides rigid, rattle-free compartmentalization for charging cables, mobile connectors, tools, emergency kits, groceries, and travel gear.

```
+=============================================================================+
|                      MODULAR 3-TIER SYSTEM ARCHITECTURE                     |
+=============================================================================+
|                                                                             |
|   [ Tier 3: Horizontal Rails ]  ====== HR_Rail_12in ====== (Top Cap)        |
|                                         |           |                       |
|   [ Slide-In Divider Panels ]   [DIV_Crosshatch]    |  (45° Diamond Mesh)   |
|                                         |           |                       |
|   [ Tier 2: Vertical Posts ]    |-- VR_Post_Deep --|  (6.4mm Guide Slots)   |
|                                 |                   |                       |
|   [ Tier 1: Floor Trusses ]     +-- FT_Segment_12in +  (Triangular Webs)    |
|                                 |                   |                       |
|   [ Modular Junctions ]      J_Corner_90 / J_Tee_3Way / J_Cross_4Way        |
|                                                                             |
|   [ Vibration Pin Locks ]    Pin_Lock_M5 (Transverse Locking Dowels)        |
+=============================================================================+
```

### Key Engineering Features
* **Three-Tier Interlocking Topology**: Load-bearing Floor Trusses rest on the frunk carpet, Vertical Rib Posts lock into truss sockets, and Horizontal Rails tie the upper perimeter into a rigid frame.
* **15° Sliding Dovetails**: Tool-free assembly between trusses, rails, and corner/Tee/Cross junction blocks with calibrated slip tolerances.
* **Transverse Pin Locks (`Pin_Lock_M5`)**: Tapered dowel pins with pull tabs that mechanically lock joints against automotive road vibration and lateral acceleration.
* **45° Diamond Crosshatch Panels**: High strength-to-weight slide-in dividers printable without support structures on large-format 3D printers like the **Creality K2 Combo** (350 × 350 × 350 mm build volume).
* **Fully Parametric Engine (`fx`)**: Every dimension (bay spacing, frame height, slot width, dovetail clearances, mesh pitch) is dynamically linked to Fusion 360 User Parameters.

---

## 2. Installation & Script Execution in Autodesk Fusion 360

The automation script (`generate_modelx_frunk_dividers.py`) programmatically creates all user parameters, sketches, extrusions, sockets, dovetail joints, lattice meshes, and organized component structures in Autodesk Fusion 360.

### 2.1 Locating Fusion 360's Scripts Directory

Autodesk Fusion 360 looks for Python scripts in specific user directory paths depending on your operating system:

| Operating System | Default Fusion 360 Scripts Directory Path |
| :--- | :--- |
| **Windows 10 / 11** | `%APPDATA%\Autodesk\Autodesk Fusion 360\API\Scripts\`<br>`C:\Users\<YourUsername>\AppData\Roaming\Autodesk\Autodesk Fusion 360\API\Scripts\` |
| **macOS** | `~/Library/Application Support/Autodesk/Autodesk Fusion 360/API/Scripts/` |

### 2.2 Step-by-Step Installation

#### Method A: Directory Copy / Link (Recommended)
1. Open your terminal or file explorer.
2. Create a folder named `modelx_frunk_dividers` inside Fusion 360's `Scripts` directory:
   * **Windows (PowerShell)**:
     ```powershell
     $target = "$env:APPDATA\Autodesk\Autodesk Fusion 360\API\Scripts\modelx_frunk_dividers"
     New-Item -ItemType Directory -Force -Path $target
     Copy-Item -Path "C:\Users\lucas\source\repos\modelx_frunk\fusion_scripts\*" -Destination $target -Recurse
     ```
   * **macOS (Terminal)**:
     ```bash
     mkdir -p ~/Library/Application\ Support/Autodesk/Autodesk\ Fusion\ 360/API/Scripts/modelx_frunk_dividers
     cp -r /path/to/modelx_frunk/fusion_scripts/* ~/Library/Application\ Support/Autodesk/Autodesk\ Fusion\ 360/API/Scripts/modelx_frunk_dividers/
     ```

#### Method B: Direct Script Open in Fusion 360
1. Launch **Autodesk Fusion 360**.
2. Press `Shift + S` (<kbd>Shift</kbd> + <kbd>S</kbd>) (or navigate to **Utilities** > **Scripts and Add-Ins** in the toolbar, or **Automation** > **Scripts and Add-Ins** in newer UI layouts).
3. Under the **Scripts** tab, click the **+** (Create/Add) button next to **My Scripts**.
4. Browse to `C:\Users\lucas\source\repos\modelx_frunk\fusion_scripts\generate_modelx_frunk_dividers.py` and select it.

```
+-----------------------------------------------------------------------+
| Scripts and Add-Ins                                              [X]  |
+-----------------------------------------------------------------------+
|  Scripts  |  Add-Ins  |                                               |
|                                                                       |
|  My Scripts                                                           |
|    > modelx_frunk_dividers                                            |
|        generate_modelx_frunk_dividers.py   [Python]                   |
|                                                                       |
|  [ Run ]   [ Debug ]   [ Edit ]   [ Create ]   [ + (Add) ]   [ Close ]|
+-----------------------------------------------------------------------+
```

### 2.3 Running the Script

1. In Fusion 360, create a new empty design document (**File** > **New Design** or <kbd>Ctrl</kbd> + <kbd>N</kbd>).
2. Open **Scripts and Add-Ins** (<kbd>Shift</kbd> + <kbd>S</kbd>).
3. Select `generate_modelx_frunk_dividers` under **My Scripts**.
4. Click **Run**.
5. The script automatically executes the parametric pipeline:
   * Populates **User Parameters (`fx`)**.
   * Creates 6 root-level component classes (8 distinct functional parts).
   * Generates sketches, triangular web profiles, 15° dovetail tabs/pockets, guide channels, tenons, and diamond crosshatch lines.
   * Displays a confirmation dialog: `Tesla Model X Frunk Divider System generated successfully!`.

### 2.4 Standalone Dry-Run / Headless Verification

You can also run the script outside Fusion 360 in standard Python (3.9+) to verify geometry calculations, parameters, and component definitions:

```bash
cd C:\Users\lucas\source\repos\modelx_frunk
python fusion_scripts\generate_modelx_frunk_dividers.py
```

---

## 3. Parametric User Parameters (`fx`) Reference

All geometric relationships are controlled by global User Parameters in Fusion 360.

### 3.1 Accessing Parameters in Fusion 360

1. In the Fusion 360 toolbar, navigate to **Modify** > **Change Parameters** (or click the **$f_x$** icon in the ribbon).
2. The **Parameters** dialog opens, displaying **User Parameters** and **Model Parameters**.
3. Edit any expression in the **Expression** column. All downstream components, sketches, extrusions, and joints immediately update in real-time.

```
+------------------------------------------------------------------------------------------------------+
| Parameters (fx)                                                                                 [X]  |
+------------------------------------------------------------------------------------------------------+
| User Parameters                                                                                      |
|   Name              | Unit | Expression | Value     | Comments                                       |
|   ------------------+------+------------+-----------+----------------------------------------------- |
|   BaySpacing        | mm   | 304.80 mm  | 304.8 mm  | Center-to-center bay spacing (12.0 in nominal) |
|   FrameHeight       | mm   | 280.00 mm  | 280.0 mm  | Frame overall height (11.0 in nominal)         |
|   TrussHeight       | mm   | 35.00 mm   | 35.0 mm   | Floor truss structure height                   |
|   TrussWidth        | mm   | 24.00 mm   | 24.0 mm   | Floor truss and rail profile width             |
|   SlotWidth         | mm   | 6.40 mm    | 6.4 mm    | Guide slot width (5mm panel + 0.7mm clearance) |
|   SlotDepth         | mm   | 8.00 mm    | 8.0 mm    | Guide slot insertion depth                     |
|   PanelThickness    | mm   | 5.00 mm    | 5.0 mm    | Nominal divider panel thickness                |
|   PanelWidth        | mm   | 298.00 mm  | 298.0 mm  | Divider panel overall width                    |
|   PanelHeight       | mm   | 275.00 mm  | 275.0 mm  | Divider panel overall height                   |
|   LatticePitch      | mm   | 18.00 mm   | 18.0 mm   | 45-degree diamond mesh pitch                   |
|   LatticeStrut      | mm   | 3.50 mm    | 3.5 mm    | Diamond mesh strut width                       |
|   TolDovetail       | mm   | 0.25 mm    | 0.25 mm   | 3D printing slip clearance for 15-deg dovetail |
|   TolTenon          | mm   | 0.20 mm    | 0.20 mm   | 3D printing slip clearance for vertical socket |
|   PinDiameter       | mm   | 5.00 mm    | 5.0 mm    | Transverse locking pin nominal diameter        |
|   DovetailBaseWidth | mm   | 14.00 mm   | 14.0 mm   | Dovetail root width                            |
|   DovetailDepth     | mm   | 8.00 mm    | 8.0 mm    | Dovetail tab depth                             |
|   DovetailAngle     | deg  | 15.00 deg  | 15.0 deg  | Dovetail wedge flare half-angle                |
|   WallClearance     | mm   | 12.70 mm   | 12.7 mm   | 0.50 in inward clearance from frunk tub wall   |
|   TrackWidth        | mm   | 30.00 mm   | 30.0 mm   | Conformal floor track rigid profile width      |
|   TrackHeight       | mm   | 18.00 mm   | 18.0 mm   | Conformal floor track rigid profile height     |
|   TrackRailBase     | mm   | 14.00 mm   | 14.0 mm   | Captive sliding top rail base width            |
|   TrackRailNeck     | mm   | 8.00 mm    | 8.0 mm    | Captive sliding top rail neck width            |
|   TrackRailHeight   | mm   | 5.00 mm    | 5.0 mm    | Captive sliding top rail guide depth           |
|   TrackBedMaxDim    | mm   | 310.00 mm  | 310.0 mm  | Max print bed envelope limit (Creality K2)     |
|   TolSeamDovetail   | mm   | 0.20 mm    | 0.20 mm   | 3D printing slip clearance for track seams     |
|   SeamDovetailAngle | deg  | 15.00 deg  | 15.0 deg  | Quadrant interlocking dovetail taper angle     |
+------------------------------------------------------------------------------------------------------+
```

### 3.2 Detailed Parameter Dictionary

| Parameter Name | Default Value | Unit | Description & Engineering Purpose |
| :--- | :--- | :--- | :--- |
| `BaySpacing` | `304.80` | `mm` | Center-to-center grid spacing (12.0 inches). |
| `FrameHeight` | `280.00` | `mm` | Total vertical height from frunk floor (11.0 inches). |
| `TrussHeight` | `35.00` | `mm` | Height of the base floor truss. |
| `TrussWidth` | `24.00` | `mm` | Structural profile width for trusses and rails. |
| `SlotWidth` | `6.40` | `mm` | Width of vertical and horizontal guide channels. |
| `SlotDepth` | `8.00` | `mm` | Depth of panel engagement slots. |
| `PanelThickness` | `5.00` | `mm` | Nominal thickness of the divider panel. |
| `PanelWidth` | `298.00` | `mm` | Overall divider panel width. |
| `PanelHeight` | `275.00` | `mm` | Overall divider panel height. |
| `LatticePitch` | `18.00` | `mm` | Pitch between adjacent 45° diamond struts. |
| `LatticeStrut` | `3.50` | `mm` | Width of each diamond lattice strut. |
| `TolDovetail` | `0.25` | `mm` | Radial clearance on 15° dovetail joints. |
| `TolTenon` | `0.20` | `mm` | Radial clearance on 20×20mm vertical sockets. |
| `PinDiameter` | `5.00` | `mm` | Nominal diameter of transverse locking pins. |
| `DovetailBaseWidth` | `14.00` | `mm` | Root width of 15° dovetail wedge. |
| `DovetailDepth` | `8.00` | `mm` | Total longitudinal extension of dovetail tab. |
| `DovetailAngle` | `15.00` | `deg` | Dovetail flare half-angle. |
| `WallClearance` | `12.70` | `mm` | Inward offset distance from calibrated LiDAR tub perimeter ($0.50\text{ in}$). |
| `TrackWidth` | `30.00` | `mm` | Total width of the conformal perimeter floor track ring. |
| `TrackHeight` | `18.00` | `mm` | Total vertical height of the conformal floor track. |
| `TrackRailBase` | `14.00` | `mm` | Bottom base width of top captive sliding T-rail groove. |
| `TrackRailNeck` | `8.00` | `mm` | Top slot opening width of captive sliding T-rail groove. |
| `TrackRailHeight` | `5.00` | `mm` | Internal depth of top captive sliding T-rail channel. |
| `TrackBedMaxDim` | `310.00` | `mm` | Max bounding dimension for Creality K2 bed compatibility. |
| `TolSeamDovetail` | `0.20` | `mm` | 3D printing slip clearance on quadrant seam joints. |
| `SeamDovetailAngle` | `15.00` | `deg` | Taper angle of quadrant interlocking dovetail seam tabs. |

---

### 3.3 Tolerance & Printer Calibration Guide

Different 3D printers and filaments exhibit varying shrinkage, extrusion widths, and layer expansion. Use the following guide to fine-tune tolerances in the **Parameters** window:

```
                            TOLERANCE TUNING SPECTRUM
   [ Ultra-Tight Press-Fit ] <---------- [ Nominal ] ----------> [ Easy Slide / Loose ]
   TolDovetail: 0.15 mm                  TolDovetail: 0.25 mm    TolDovetail: 0.35 mm
   TolTenon:    0.12 mm                  TolTenon:    0.20 mm    TolTenon:    0.30 mm
   TolSeam:     0.15 mm                  TolSeam:     0.20 mm    TolSeam:     0.25 mm
```

1. **Filament Thermal Shrinkage**:
   * **ASA / ABS**: Shrinks ~0.4% to 0.7% upon cooling. Keep `TolDovetail = 0.25 mm`, `TolTenon = 0.20 mm`, and `TolSeamDovetail = 0.20 mm`. 
   * **PETG**: Shrinks ~0.2%. If joints feel tight, increase `TolDovetail` to `0.30 mm`.
2. **Printer Calibration Check**:
   * If the male tab requires excessive force: Increase `TolDovetail` / `TolSeamDovetail` by `+0.05 mm`.
   * If the joint wobbles: Decrease `TolDovetail` / `TolSeamDovetail` by `-0.05 mm`.

---

## 4. Component Library & Functional Specifications

The generator script produces 13 distinct CAD solid bodies organized in the Fusion 360 browser tree:

```
Browser
 ├── (o) Unsaved [Active Design]
 ├── (o) Bodies
 │    ├── FT_Segment_12in          <-- 12" Floor Truss Beam
 │    ├── VR_Post_Deep             <-- 11" Vertical Post with 6.4mm Slots
 │    ├── HR_Rail_12in             <-- 12" Horizontal Top Rail
 │    ├── J_Corner_90              <-- 2-Way 90° Corner Block
 │    ├── J_Tee_3Way               <-- 3-Way T-Junction Block
 │    ├── J_Cross_4Way             <-- 4-Way Cross Junction Block
 │    ├── DIV_Crosshatch_12x11     <-- Slide-in Diamond Mesh Divider Panel
 │    ├── Pin_Lock_M5              <-- Transverse Locking Pin
 │    ├── TRK_Front_L              <-- Conformal Track Front-Left Quadrant
 │    ├── TRK_Front_R              <-- Conformal Track Front-Right Quadrant
 │    ├── TRK_Rear_L               <-- Conformal Track Rear-Left Quadrant
 │    ├── TRK_Rear_R               <-- Conformal Track Rear-Right Quadrant
 │    └── TRK_Master_Assembled     <-- 360° Continuous Perimeter Floor Track Ring
```

### Component Details

```
+---------------------------------------------------------------------------------------------------+
| 1. FT_Segment_12in (Floor Truss Segment)                                                          |
|    - Envelope: 304.8 mm (L) × 24.0 mm (W) × 35.0 mm (H)                                          |
+---------------------------------------------------------------------------------------------------+
| 2. VR_Post_Deep (Vertical Rib Post)                                                               |
|    - Envelope: 24.0 mm (W) × 24.0 mm (D) × 280.0 mm (H)                                          |
+---------------------------------------------------------------------------------------------------+
| 3. HR_Rail_12in (Horizontal Top Rail)                                                             |
|    - Envelope: 304.8 mm (L) × 24.0 mm (W) × 24.0 mm (H)                                          |
+---------------------------------------------------------------------------------------------------+
| 4. J_Corner_90, J_Tee_3Way, J_Cross_4Way (Modular Junction Blocks)                                |
|    - Envelope: 32.0 mm × 32.0 mm × 35.0 mm                                                        |
+---------------------------------------------------------------------------------------------------+
| 5. DIV_Crosshatch_12x11 (Slide-In Diamond Mesh Divider)                                           |
|    - Envelope: 298.0 mm (W) × 275.0 mm (H) × 5.0 mm (T)                                          |
+---------------------------------------------------------------------------------------------------+
| 6. Pin_Lock_M5 (Transverse Locking Pin)                                                           |
|    - Envelope: 8.0 mm cap diameter × 32.0 mm total length                                         |
+---------------------------------------------------------------------------------------------------+
| 7. TRK_Front_L, TRK_Front_R, TRK_Rear_L, TRK_Rear_R (Conformal Floor Track Quadrants)              |
|    - Profile: 30.0 mm wide × 18.0 mm high rigid anti-tip profile with captive sliding top rail    |
|      (14mm base, 8mm neck, 5mm depth) and 15° interlocking dovetail seam tabs/pockets.            |
+---------------------------------------------------------------------------------------------------+
| 8. TRK_Master_Assembled (Continuous Master Perimeter Floor Ring)                                  |
|    - Features: 360° closed contour matching 2017 Model X AWD frunk floor with 12.7 mm clearance.  |
+---------------------------------------------------------------------------------------------------+
```

---

## 5. Multi-Bay Assembly & Expansion Guide

Using Fusion 360's native **Joint** tools, you can assemble any custom grid configuration and inspect the conformal perimeter track for the Tesla Model X frunk tub.

### 5.1 Fusion 360 Joint Assembly Workflow

1. **Ground the Base Component**:
   * In the browser tree, right-click the first corner block (`J_Corner_90:1`) or floor truss and select **Ground**. This fixes its coordinate frame in 3D space.
2. **Create Rigid Joints for Dovetails**:
   * Press <kbd>J</kbd> (or select **Assemble** > **Joint**).
   * **Motion Type**: `Rigid`.
   * **Snap Point 1**: Select the center Joint Origin on the root face of the male dovetail tab.
   * **Snap Point 2**: Select the corresponding Joint Origin on the female dovetail pocket.
   * The components will snap together flush.
3. **Assemble Vertical Posts**:
   * Press <kbd>J</kbd> (`Rigid Joint`).
   * Select the bottom face center of the vertical post tenon (`VR_Post_Deep`).
   * Select the floor socket center on the truss or junction block.
4. **Insert Locking Pins**:
   * Align `Pin_Lock_M5` with the transverse 5.0mm holes on the sockets.
5. **Slide-In Divider Panels**:
   * For dynamic simulation: Create a **Slider Joint** along the vertical Z-axis between the panel side edge and the post guide slot. Set motion limits between $Z = 0\text{ mm}$ and $Z = 280\text{ mm}$.
6. **Assemble Conformal Floor Track Quadrants**:
   * In Fusion 360, make `TRK_Front_L`, `TRK_Front_R`, `TRK_Rear_L`, and `TRK_Rear_R` visible.
   * Apply a **Rigid Joint** (<kbd>J</kbd>) between the Front seam dovetail faces of `TRK_Front_L` and `TRK_Front_R`.
   * Apply Rigid Joints sequentially to the Right, Rear, and Left dovetail seams to close the continuous loop.
   * Inspect clearance against the calibrated mesh overlay `docs/scans/frunk_scan_calibrated.stl` to verify uniform $12.7\text{ mm}$ wall clearance.

---

### 5.2 Standard Layout Configurations & Bill of Materials (BOM)

```
+=============================================================================+
|                      STANDARD FRUNK GRID CONFIGURATIONS                     |
+=============================================================================+

   [ Layout A: 1x1 Single Bay ]           [ Layout B: 2x1 Dual Bay ]
   +--------------------------+           +--------------------------+--------------------------+
   | (J_C)=== HR_Rail ===(J_C)|           | (J_C)=== HR_Rail ===(J_T)=== HR_Rail ===(J_C)|
   |  ||                  ||  |           |  ||                  ||                  ||  |
   |  ||  DIV_Crosshatch  ||  |           |  ||     Bay 1        ||     Bay 2        ||  |
   |  ||                  ||  |           |  ||  DIV_Crosshatch  ||  DIV_Crosshatch  ||  |
   | (J_C)=== HR_Rail ===(J_C)|           | (J_C)=== HR_Rail ===(J_T)=== HR_Rail ===(J_C)|
   +--------------------------+           +--------------------------+--------------------------+
   Footprint: ~336 × 336 mm               Footprint: ~640 × 336 mm

   [ Layout C: 2x2 Four-Bay Grid (Recommended for Model X AWD Tub) ]
   +--------------------------+--------------------------+
   | (J_C)=== HR_Rail ===(J_T)=== HR_Rail ===(J_C)|
   |  ||                  ||                  ||  |
   |  ||     Bay (1,1)    ||     Bay (1,2)    ||  |
   |  ||  [Mobile Connect]||  [Emergency Gear]||  |
   | (J_T)=== HR_Rail ===(J_X)=== HR_Rail ===(J_T)|
   |  ||                  ||                  ||  |
   |  ||     Bay (2,1)    ||     Bay (2,2)    ||  |
   |  ||  [Tire Inflator] ||  [Shopping Bags] ||  |
   | (J_C)=== HR_Rail ===(J_T)=== HR_Rail ===(J_C)|
   +--------------------------+--------------------------+
   Footprint: ~640 × 640 mm (Fills lower frunk tub)

   [ Layout D: 2x3 Six-Bay High-Density Grid ]
   +--------------------------+--------------------------+--------------------------+
   | (J_C)=== HR_Rail ===(J_T)=== HR_Rail ===(J_T)=== HR_Rail ===(J_C)|
   |  ||      Bay 1       ||      Bay 2       ||      Bay 3       ||  |
   | (J_T)=== HR_Rail ===(J_X)=== HR_Rail ===(J_X)=== HR_Rail ===(J_T)|
   |  ||      Bay 4       ||      Bay 5       ||      Bay 6       ||  |
   | (J_C)=== HR_Rail ===(J_T)=== HR_Rail ===(J_T)=== HR_Rail ===(J_C)|
   +--------------------------+--------------------------+--------------------------+
   Footprint: ~640 × 945 mm
```

#### Bill of Materials (BOM) Summary Table

| Component Name | Description | 1×1 Single | 2×1 Dual | 2×2 Grid (Full Frunk) | 2×3 High-Density |
| :--- | :--- | :---: | :---: | :---: | :---: |
| `FT_Segment_12in` | 12" Floor Truss Beam | 4 | 7 | 12 | 17 |
| `VR_Post_Deep` | 11" Vertical Post Column | 4 | 6 | 9 | 12 |
| `HR_Rail_12in` | 12" Horizontal Top Rail | 4 | 7 | 12 | 17 |
| `J_Corner_90` | 2-Way 90° Corner Block | 4 | 4 | 4 | 4 |
| `J_Tee_3Way` | 3-Way T-Junction Block | 0 | 2 | 4 | 6 |
| `J_Cross_4Way` | 4-Way Cross Junction Block | 0 | 0 | 1 | 2 |
| `DIV_Crosshatch_12x11` | Removable Divider Panel | 1 to 4 | 2 to 7 | 4 to 12 | 6 to 17 |
| `Pin_Lock_M5` | M5 Locking Pin | 8 | 14 | 22 | 30 |
| `TRK_Front_L` | Conformal Track Front-Left | 1 | 1 | 1 | 1 |
| `TRK_Front_R` | Conformal Track Front-Right | 1 | 1 | 1 | 1 |
| `TRK_Rear_L` | Conformal Track Rear-Left | 1 | 1 | 1 | 1 |
| `TRK_Rear_R` | Conformal Track Rear-Right | 1 | 1 | 1 | 1 |

---

## 6. Exporting for 3D Printing & Manufacturing

To transfer your parts to slicers (Creality Print, OrcaSlicer, PrusaSlicer, Bambu Studio), use either **Binary 3MF** or **STEP** export.

### 6.1 Exporting as 3MF (Recommended)

3MF preserves exact millimeter scaling, component names, color metadata, and high-density curved surfaces without file bloat.

1. In the Fusion 360 Browser tree, expand the **Bodies** folder.
2. Right-click the component or body you want to export (e.g. `FT_Segment_12in` or `TRK_Front_L`).
3. Select **Save As Mesh**.
4. Configure the **Save As Mesh** dialog options:
   * **Format**: `3MF (3D Manufacturing Format)`
   * **Unit**: `Millimeter`
   * **Structure**: `One File Per Body` / `One File Per Component`
   * **Refinement**: `High`
     * *Optional Custom Refinement*:
       * Surface Deviation: $\le 0.01\text{ mm}$
       * Normal Deviation: $\le 10.0^\circ$
       * Maximum Edge Length: $10.0\text{ mm}$
5. Click **OK** and save to your project directory.
6. Repeat for `TRK_Front_R`, `TRK_Rear_L`, and `TRK_Rear_R` to produce the full printable track quadrant set.

```
+-----------------------------------------------------------------------+
| Save As Mesh                                                     [X]  |
+-----------------------------------------------------------------------+
|  Format:        [ 3MF (3D Manufacturing Format)           v ]         |
|  Unit Type:     [ Millimeter                              v ]         |
|  Structure:     [ One File Per Component                  v ]         |
|  Refinement:    [ High                                    v ]         |
|                                                                       |
|  Output:                                                              |
|  [X] Send to 3D Print Utility (Creality Print / OrcaSlicer)           |
|                                                                       |
|                                [ OK ]     [ Cancel ]                  |
+-----------------------------------------------------------------------+
```

### 6.2 Exporting as STEP (`.step` / `.stp`)

Modern slicers (OrcaSlicer, Creality Print, Bambu Studio) support direct STEP CAD geometry import, generating pristine toolpaths directly from mathematical surfaces rather than tessellated polygons:

1. Right-click the component > **Export**.
2. Set **Type** to `STEP Files (*.step, *.stp)`.
3. Select your destination directory and click **Export**.

---

### 6.3 Creality K2 Combo Build Orientation Guidelines

The **Creality K2 Combo** features a large **350 × 350 × 350 mm** build volume, allowing all components of this system—including all 4 conformal floor track quadrants—to be printed flat on the bed with **zero support material**.

```
+=============================================================================+
|                 CREALITY K2 BUILD PLATE PLACEMENT STRATEGY                  |
+=============================================================================+

  [ 1. FT_Segment_12in (304.8mm) ]      [ 2. DIV_Crosshatch_12x11 (298x275mm) ]
  +-------------------------------+     +-------------------------------------+
  | [Triangles] [Socket] [DT]     |     | [========= Finger Pull ==========]  |
  +-------------------------------+     |  /\  /\  /\  /\  /\  /\  /\  /\  /\ |
  Bed Contact: Flat base on bed         |  \/  \/  \/  \/  \/  \/  \/  \/  \/ |
  Supports: ZERO required               |  45° Self-Supporting Diamond Mesh   |
                                        +-------------------------------------+
                                        Bed Contact: Flat face (5.0mm high)
                                        Supports: ZERO required

  [ 3. VR_Post_Deep (280mm) ]           [ 4. Conformal Track Quads (<310mm) ]
  +-------------------------------+     +-------------------------------------+
  | Tenon | === Slots === | Pin   |     | ~~~~~~ 15° Dovetail Arc ~~~~~~     |
  +-------------------------------+     +-------------------------------------+
  Bed Contact: Lay flat on side         Bed Contact: Flat bottom base
  Supports: ZERO required               Supports: ZERO required (<310 mm bed)
```

* **Floor Trusses (`FT_Segment_12in`)**: Place flat on bottom surface. Triangular cutouts bridge at 45° angles without sagging.
* **Vertical Posts (`VR_Post_Deep`)**: Place flat horizontally on one face. The 6.4mm slots run parallel to the build plate and bridge cleanly.
* **Divider Panels (`DIV_Crosshatch_12x11`)**: Lay flat on build plate (Z-height = 5.0mm). 45° diamond struts print continuously as self-supporting infill.
* **Conformal Track Quadrants (`TRK_Front_L`, `TRK_Front_R`, `TRK_Rear_L`, `TRK_Rear_R`)**: Place flat on the bottom base. Max oriented bounding dimension is $\le 310\text{ mm}$, easily fitting within the $350 \times 350\text{ mm}$ bed envelope. The top captive rail groove and 15° dovetail end joints print with 0 supports.
* **Junction Blocks (`J_Corner_90`, `J_Tee_3Way`, `J_Cross_4Way`)**: Print standing upright on bottom base.
* **Locking Pins (`Pin_Lock_M5`)**: Print standing upright with a 3mm brim, or lying flat in batches of 10.

---

## 7. Troubleshooting & FAQ

### Q1: The Python script shows an error about missing `geometry_calc` or `conformal_track_calc`.
* **Fix**: Ensure that `geometry_calc.py` and `conformal_track_calc.py` are in the same directory as `generate_modelx_frunk_dividers.py`, or run `fusion_scripts/ModelX_Frunk_Dividers_Standalone.py` which contains the standalone self-contained engine.

### Q2: Changing `BaySpacing` causes a downstream extrusion error.
* **Cause**: Changing `BaySpacing` to a very small value ($<150\text{ mm}$) may cause the 6 triangular truss cutouts to overlap.
* **Fix**: Keep `BaySpacing` between `200.0 mm` and `400.0 mm`. For smaller compartments, use 12" bays with multiple internal slot dividers.

### Q3: Dovetails or Track Seams fit too tightly or require excessive force.
* **Fix**: Open **Modify** > **Change Parameters** (`fx`). Increase `TolDovetail` or `TolSeamDovetail` from `0.20 mm` to `0.25 mm` or `0.30 mm`. Re-export the 3MF mesh and slice.

### Q4: Does this system fit the refreshed (2021+) Model X frunk?
* **Answer**: The 2021+ refreshed Model X frunk is slightly wider and shallower. By adjusting `FrameHeight` to `230.0 mm` and `BaySpacing` to `320.0 mm` in the parameters window, the modular framework adapts directly to newer vehicle geometries.

---

*Document Revision: 1.1.0 — Automated Parametric Engine & Conformal Floor Track for Tesla Model X Frunk Storage.*

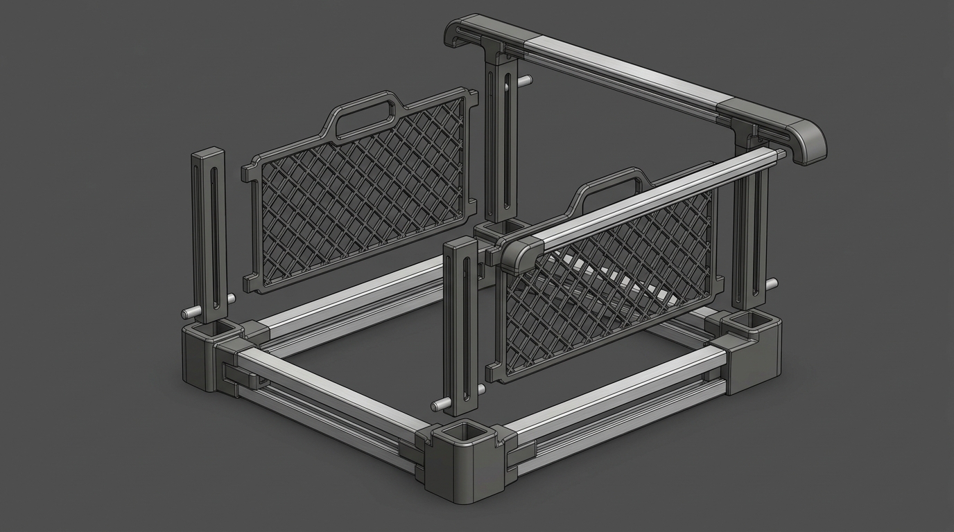
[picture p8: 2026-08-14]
docs/images/frunk_divider_assembled.jpg

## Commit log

2026-08-14 feat(cad): add parametric geometry and coordinate engine for Model X frunk dividers
2026-08-14 feat(fusion360): implement complete automated CAD generation script for Model X frunk system
2026-08-14 docs(cad): add comprehensive Fusion 360 user and parametric reference guide
2026-08-14 docs(3dprint): add Creality K2 slicing and ASA/ABS/PETG printing guide
2026-08-14 docs: add project README, Bill of Materials, and assembly architecture
2026-08-14 feat(fusion): update ModelX_Frunk_Dividers.py with complete CAD generation code
2026-08-14 fix(fusion): enable parametric assembly mode and robust component creation to resolve Part Design single-component error
2026-08-14 feat(cad): arrange components with distinct spatial layout offsets and named solid bodies
2026-08-14 feat(cad): execute full through-all boolean cuts for diamond lattice mesh and truss webs
2026-08-14 fix(fusion): use ObjectCollection batch cut in +Z to punch all 182 diamond apertures and symmetric truss webs
2026-08-14 fix(cad): use rotated grid math for uniform 45-degree diagonal struts with clean handle clearance and span truss webs
2026-08-14 fix(cad): edge-to-edge diamond lattice tiling across full panel and solid truss chords
2026-08-14 docs: add rendered assembly and in-situ frunk installation images
2026-08-15 feat(scan): extract, calibrate and analyze Tesla Model X 2017 frunk LiDAR scan dimensions
    [frunk_scan.obj, frunk_scan.stl, frunk_scan_aligned.stl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]
2026-08-15 docs(spec): add conformal track and sliding modular divider system design specification
2026-08-15 docs(plan): add conformal floor track implementation plan
2026-08-15 docs(spec): specify rigid rectangular track profile for anti-tilt post stability
2026-08-15 feat(conformal-track): implement LiDAR floor contour extraction and inset geometry engine
2026-08-15 feat(conformal-track): implement quadrant slicing and 15° interlocking seam geometry engine
2026-08-15 feat(fusion): automated solid generation for conformal floor track and native script deployment
2026-08-15 docs(conformal-track): document LiDAR floor track parameters, assembly, and slicing matrix
2026-08-15 fix(cad): use smooth fitted closed loops for conformal floor track solid extrusion and dovetail seams
2026-08-15 feat(cad): flanged anti-tilt floor rail profile and captive sliding post shoe assembly
2026-08-15 fix(cad): ensure all 4 floor track quadrants have continuous upper neck layer and watertight dovetails
2026-08-15 feat(cad): separate components, captive slotted post base shoe, and interlocking 6in cross slats
2026-08-15 fix(cad): universal BRep solid body creation compatible with Part Design documents and explicit CombineFeatures
2026-08-15 fix(cad): scale dovetails for 16mm upper neck so all 4 quadrants generate complete two-tier stepped T-rail
2026-08-15 fix(cad): perfectly align sliding post base shoe tunnel and orient 6in cross slat to guide channel
2026-08-15 feat(cad): one-click batch 3MF exporter script for Fusion 360
2026-08-15 feat(cad): break floor track down into 10 super-compact modular segments all under 185mm
